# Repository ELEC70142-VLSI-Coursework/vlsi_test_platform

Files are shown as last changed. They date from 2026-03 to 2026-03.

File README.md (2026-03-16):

# VLSI Test Platform

A complete hardware and software solution for bringing up and testing the VLSI SoC Project IC. This repository contains the FPGA firmware, Python host tools, and hardware design documentation.

## System Overview

The test platform consists of three integrated components:

<div align="center">
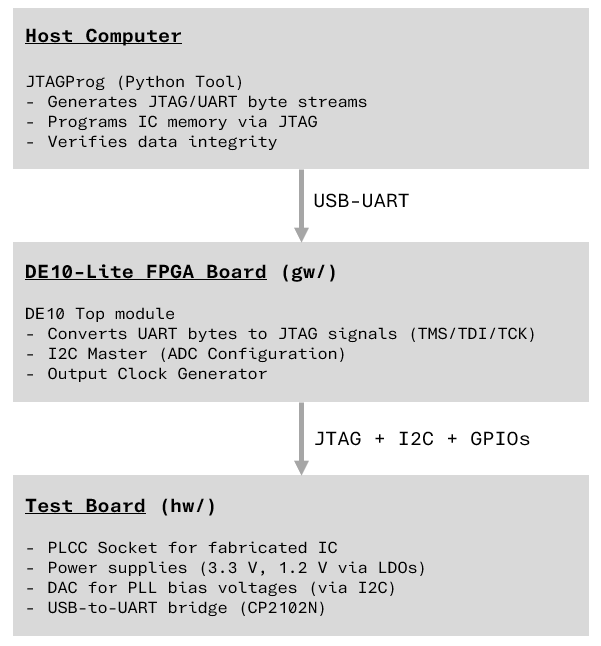
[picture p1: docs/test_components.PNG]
    
</div>

## Directory Structure

```
vlsi_test_platform/
├── gw/                    # FPGA Firmware (DE10-Lite)
│   ├── src/              # SystemVerilog modules
│   │   ├── DE10Top.sv    # Top-level module
│   │   ├── jtag_uart_bridge.sv
│   │   ├── jtag_engine.sv
│   │   ├── adc_commander.sv
│   │   ├── i2c_master.sv
│   │   └── uart_*.sv     # UART controller modules
│   ├── test/             # DUT (Device Under Test) bitstreams
│   └── README.md         # FPGA documentation
│
├── sw/                    # Host-Side Python Tools
│   ├── JTAGProg.py       # JTAG programmer and tester
│   └── README.md         # Python tool documentation
│
├── hw/                    # Test Board PCB Design
│   ├── [Schematic/Layout files]
│   └── README.md         # Hardware documentation
│
└── README.md             # This file
```

## Quick Start

### Prerequisites

1. **Hardware**: DE10-Lite FPGA board and VLSI test board
2. **Software**: Quartus Prime, Python 3.6+, pyserial

### 1. Program the FPGA

1. Load the compiled FPGA design (`.sof` file) onto the DE10-Lite using Quartus Programmer
2. The FPGA automatically configures the test board DAC after reset
3. Verify that the USB-UART bridge is recognized on your host computer

### 2. Program the IC via JTAG

```bash
# Test mode: verify JTAG communication with a known pattern
python JTAGProg.py COM4 --test-mode --word-count 256

# Load mode: program memory from a hex file
python JTAGProg.py COM4 program.hex
```

See [sw/README.md](sw/README.md) for full usage details.

### 3. Verify the Setup

- Check that the test board LEDs indicate correct power and USB connection
- Monitor JTAG read/write throughput in the python interface output
- Inspect the IC power supplies and clock signals with an oscilloscope if needed

## Component Details

### FPGA Firmware (gw/)

The DE10-Lite FPGA implements:
- **UART-to-JTAG Bridge**: Converts serial bytes to JTAG protocol for IC programming
- **I2C Master**: Configures the DAC for PLL bias voltages
- **Clock Generator**: Produces a test clock output

[Read more](gw/README.md)

### Python Host Tool (sw/)

`JTAGProg.py` provides:
- **Test Mode**: Random write/read verification for JTAG communication
- **Load Mode**: Program IC memory from a plain-text hex file
- **Performance Monitoring**: Reports read/write throughput and errors

[Read more](sw/README.md)

### Test Board Hardware (hw/)

The PCB includes:
- PLCC socket for the VLSI IC
- Power management (3.3 V and 1.2 V LDOs)
- DAC for PLL bias voltage tuning
- USB-to-UART bridge (CP2102N)
- FPGA connector for control signals (JTAG, I2C, clock)
- Reset button and DIP switch for PLL frequency selection

[Read more](hw/README.md)

## References

- Altera DE10-Lite Board: [User Manual](https://www.intel.com/content/www/us/en/programmable/documentation/boards/de10_lite_user_manual.pdf)
- CP2102N USB-UART IC: [Datasheet](https://www.silabs.com/documents/public/data-sheets/cp2102n-datasheet.pdf)
- DAC7578 DAC IC: [Datasheet](https://www.ti.com/lit/ds/symlink/dac7578.pdf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)

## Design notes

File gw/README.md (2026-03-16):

# FPGA Control Firmware for VLSI Test Platform

This directory contains the SystemVerilog modules that implement the control firmware for the VLSI Module Project IC test platform. The design runs on the DE10-Lite FPGA board and provides the following core functionality:

- **ADC Configuration**: Configures the bias voltages for the PLL via I2C protocol
- **UART-to-JTAG Bridge**: Bridges serial communication to JTAG for IC programming and testing
- **Generated Clock Output**: Provides a configurable clock signal for testing

## Module Overview

| Module | File | Purpose |
|---|---|---|
| `DE10Top` | `DE10Top.sv` | Top-level module integrating all components |
| `adc_commander` | `adc_commander.sv` | Manages I2C communication with the ADC for PLL bias voltage configuration |
| `i2c_master` | `i2c_master.sv` | I2C protocol controller |
| `jtag_uart_bridge` | `jtag_uart_bridge.sv` | Converts UART byte stream to JTAG signals (TMS, TDI, TCK, TDO) |
| `jtag_engine` | `jtag_engine.sv` | Low-level JTAG state machine controller |
| `uart_rx` / `uart_tx` | `uart_rx.sv`, `uart_tx.sv` | UART serial communication |
| `rx_fifo` / `tx_fifo` | `rx_fifo.sv`, `tx_fifo.sv` | Synchronous FIFOs for UART buffering |

## Clock Generation

The design generates an internal 10 MHz clock using the Quartus PLL IP (`pll_clk`). An additional output clock (`clk_out`) is generated at 100 kHz and output to pin Y5 (IC package pin 43). The output clock frequency can be modified by changing the `OUTPUT_CLK_FREQ` parameter in `DE10Top.sv`.

**Note**: The Quartus IP generator may not generate the PLL IP correctly. Verify that the output frequency matches the expected value before deployment.

## I2C and ADC Commander

The ADC on the test board configures the PLL bias voltages via the I2C protocol. The `adc_commander` module orchestrates this configuration by sending commands through the `i2c_master` module.

- **Bias Voltage Configuration**: Two 12-bit voltage values are configured via I2C
- **Experimental Tuning**: Voltage values should be calibrated based on measurements on the actual IC

For details on command sequences, refer to `adc_commander.sv`.

## UART Connectivity

The test board includes a USB-UART bridge IC (CP2102N) connected to the FPGA:

| FPGA Port | CP2102N Pin | Direction |
|---|---|---|
| `uart_rx` | Y6 | Input (from host) |
| `uart_tx` | Y7 | Output (to host) |

**Note**: Pin assignments swap the physical connections; the FPGA perspective labels (`uart_rx`, `uart_tx`) correctly represent the data flow.

Pin assignments in the `.qpf` file:
```
set_location_assignment PIN_Y6 -to uart_rx
set_location_assignment PIN_Y7 -to uart_tx
```

## UART-to-JTAG Bridge

The `jtag_uart_bridge` module converts UART byte stream to JTAG protocol signals for IC programming and testing. Each UART byte is interpreted as:
- **High nibble (bits 7-4)**: Four TMS bits
- **Low nibble (bits 3-0)**: Four TDI bits

The `jtag_engine` module implements the JTAG state machine and handles TCK generation.

A Python driver for communicating with the bridge is provided in the `/sw` folder.

## Customizing the Design

The FPGA can be extended to drive IC inputs and process outputs based on project specifications:
- **UART Redirection**: Redirect UART ports to IC GPIO through the FPGA fabric
- **Preserve ADC Configuration**: The `adc_commander` module is required for correct PLL operation
- **Extending Functionality**: Additional logic can be instantiated in parallel with existing modules

### Pin Assignments

The following pin constraints are required for the test board:

```
set_location_assignment PIN_V7 -to rst_n
set_location_assignment PIN_P11 -to pll_clk
set_location_assignment PIN_Y6 -to uart_rx
set_location_assignment PIN_Y7 -to uart_tx
set_location_assignment PIN_W11 -to sda
set_location_assignment PIN_AA10 -to scl
set_location_assignment PIN_Y5 -to clk_out 
```

All pin IO Standard must be configured on `3.3-V LVTTL`.

Mapping of pins between FPGA and IC can be found in the board [schematic](../hw/schematic.pdf)

## Testing the JTAG Interface

To test the JTAG functionality with a simulated IC memory model:

1. Prepare a second DE10-Lite board to act as a Device Under Test (DUT)
2. Load the DUT bitstream via Quartus > Tools > Programmer
3. Connect the DUT to the test board's DUT connector
4. Use the Python script (in `/sw`) to program through the UART-JTAG bridge

**Bitstream Files**:
- `.sof` (SRAM Object File): Loaded directly into FPGA RAM; erased on power-off
- `.pof` (Programmer Object File): Stored in flash memory; persists across power cycles

Use `.pof` to retain the FPGA design after power-off.

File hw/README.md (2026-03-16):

# Testboard Hardware

The testboard is an integrated solution for the **VLSI SoC Project** IC bring-up. It includes:

- PLCC socket
- LDOs for the padring and core supplies (3.3 V and 1.2 V respectively)
- Reset button
- Solderable jumper to select active-high or active-low reset
- 25 MHz crystal oscillator
- DAC to supply bias voltages to the PLL
- 4-position DIP switch for selecting the PLL frequency
- USB-to-UART bridge IC (CP2102N)
- Jumpers to select the source of the clock and 1.2 V supply (board or connector)
- Buffers for the FPGA input clock and the board output clock
- Connector for the DE10-Lite FPGA

<div align="center">
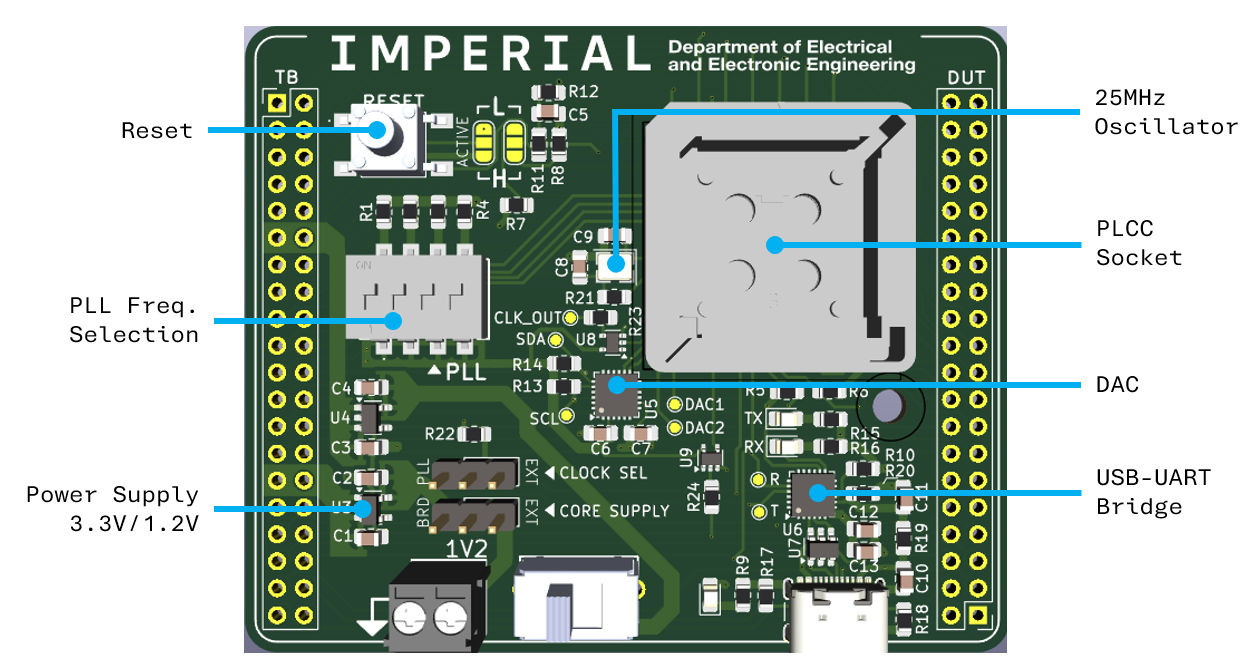
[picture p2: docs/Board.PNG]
    
</div>

## Assembly Guidelines

First, solder the SMD components using the stencil and a reflow oven. Do not place the DIP switch in the reflow oven — solder it by hand afterwards.

Once the SMD components are soldered, test the LDOs by applying 5 V and 3.3 V to connector U1 (TB). Check for shorts on the USB-C connector and verify that QFN packages U5 and U6 have no solder bridges and all pins are properly soldered. 

Set solder jumpers JP4 and JP5 to the low position, marked "L" on the silkscreen.

Next, solder the through-hole components: power switch S2, connector J2, jumpers JP1 and JP2, and the 40-pin FPGA connectors. Do not solder the PLCC socket (J4) at this stage — leaving it unsoldered allows easier access to the pin holes for testing.

Once testing is complete, solder the PLCC socket with the orientation arrow pointing down, indicating pin 1.

### Testing the DAC

The I2C DAC IC can be tested by connecting a DE10-Lite FPGA board and loading the bitstream described elsewhere in this repository. The FPGA automatically configures the DAC over I2C after reset. The DAC requires the 1.2 V supply as its reference — ensure the core-supply jumper is set to "BRD" to use the onboard LDO. Measure the DAC outputs at testpoints DAC1 and DAC2; the expected voltages are defined in [gw/src/adc_commander.sv](../gw/src/adc_commander.sv).

### Testing the USB-UART Bridge

Test the USB-UART bridge using the provided FPGA design (see elsewhere in this repository). After loading the bitstream, verify UART–JTAG communication using the Python script.

The TX/RX LEDs (D2 and D3) will not function on a newly soldered CP2102N until the IC has been configured. To configure it:

1. Install the USB-to-UART VCP drivers from [Silicon Labs](https://www.silabs.com/software-and-tools/usb-to-uart-bridge-vcp-drivers?tab=downloads).
2. Install [Simplicity Studio 5](https://www.silabs.com/software-and-tools/simplicity-studio/simplicity-studio-version-5) (not version 6).
3. Power the board and launch Simplicity Studio — it should detect the CP2102N automatically.
4. Open **Tools > Express Configurator**.
5. Under **Configuration Groupings > Port Configurations > GPIO**, set GPIO0 to "TX Toggle" and GPIO1 to "RX Toggle".
6. Click **Program to Device**.

## Suggested Improvements

Future board revisions could include:

- Decoupling capacitors between the PLCC socket supply pins and ground.
- A silkscreen mark indicating PLCC socket pin 1.
- A small series resistor between the PLCC socket clock input and the Schmitt-trigger buffer to reduce ringing.
- Additional mounting holes.

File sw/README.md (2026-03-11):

# JTAGProg — Host-Side JTAG/UART Programmer

`JTAGProg.py` is a Python tool for driving the JTAG Engine firmware module located in [gw/src/](../gw/src/) via a UART interface. A USB-to-UART bridge (e.g. FTDI or CP2102N) exposes the JTAG engine to the host as a standard serial port.

## How it works

The script contains two main classes:

- **`JTAGDriver`** — builds TMS/TDI bitstreams and packs them into bytes. Each byte encodes four JTAG clock cycles: the high nibble carries four TMS bits and the low nibble carries four TDI bits. The class provides helpers for navigating the JTAG FSM and shifting instructions and data registers.
- **`JTAGProg`** — opens a serial port and sends/receives the packed byte stream to/from the UART bridge. Read data is recovered by clocking dummy bytes into the TAP and capturing the TDO bits returned by the target device.

## Dependencies

Install the required package with:

```
pip install pyserial
```

## Usage

Run the script with `-h` to see all options:

```
python JTAGProg.py -h
```

In both modes the COM port must be specified. To list available ports:

```
python -m serial.tools.list_ports -v
```

### Test mode

Generates random 32-bit words, writes them to memory, then reads them back and verifies the contents.

```
python JTAGProg.py COM4 --test-mode --word-count 256
```

`--word-count` is optional (default: 128).

### Load mode

Writes the contents of a plain-text file containing one 32-bit hex word per line.

```
python JTAGProg.py COM4 data.hex
```

### Output

Both modes print a summary after verification:

```
Summary:
  Total words: 256
  Total bytes: 1024 (1.00 KB)
  Total write time: 1.604s
  Write throughput: 0.62 KB/s
  Total read time: 6.994s
  Read throughput: 0.14 KB/s
  Total errors: 0
```

The script exits with code `2` if any verification errors are detected, or `0` on success.

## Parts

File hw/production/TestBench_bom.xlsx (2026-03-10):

 |  |  |  |  |  |  |  |  |  | 10
Reference | Value | Footprint | Qty | Supplier | Other Supplier | SupplierPartNo | Description | UnitPrice | MinQty | Quantity | LineSum | Link
C1,C2,C4 | 1u | Capacitor_SMD:C_0805_2012Metric_Pad1.18x1.45mm_HandSolder | 3 | OneCall (Farnell and CPC) |  | 3013482 | £0.0679 - SMD Multilayer Ceramic Capacitor, 1 µF, 50 V, 0805 [2012 Metric], ± 10%, X7R | 0.046978 | 10 | 30 | 1.41 | https://uk.farnell.com/samsung-electro-mechanics/cl21b105kbfnnne/cap-1uf-50v-mlcc-0805/dp/3013482
C3,C10,C13 | 10u | Capacitor_SMD:C_0805_2012Metric_Pad1.18x1.45mm_HandSolder | 3 | OneCall (Farnell and CPC) |  | 3013485 | £0.1488 - SMD Multilayer Ceramic Capacitor, 10 µF, 16 V, 0805 [2012 Metric], ± 10%, X7R | 0.10292 | 10 | 30 | 3.09 | https://uk.farnell.com/samsung-electro-mechanics/cl21b106koqnnne/cap-10uf-16v-mlcc-0805/dp/3013485
C5,C6,C7,C11,C12 | 100n | Capacitor_SMD:C_0805_2012Metric_Pad1.18x1.45mm_HandSolder | 5 | OneCall (Farnell and CPC) |  | 4539029 | £0.0329 - SMD Multilayer Ceramic Capacitor, 0.1 µF, 50 V, 0805 [2012 Metric], ± 10%, X7R | 0.013114 | 10 | 50 | 0.66 | https://uk.farnell.com/samsung-electro-mechanics/cl21b104kbcnnnd/capacitor-mlc-0-1uf-x7r-50v-0805/dp/4539029
C8,C9 | 6p | Capacitor_SMD:C_0805_2012Metric_Pad1.18x1.45mm_HandSolder | 2 | OneCall (Farnell and CPC) |  | 1759185 | £0.054 - SMD Multilayer Ceramic Capacitor, 6 pF, 50 V, 0805 [2012 Metric], ± 0.5pF, C0G / NP0 | 0.054 | 10 | 20 | 1.08 | https://uk.farnell.com/multicomp-pro/mc0805n6r0d500ct/cap-6pf-50v-c0g-np0-0805/dp/1759185
D1,D2,D3 | LED | LED_SMD:LED_0805_2012Metric_Pad1.15x1.40mm_HandSolder | 3 | OneCall (Farnell and CPC) |  | 1226392 | £0.1548 - LED, Hyper-Bright, Red, SMD, 0805 [2012 Metric], 25 mA, 2 V, 633 nm | 0.108 | 10 | 30 | 3.24 | https://uk.farnell.com/osram-opto-semiconductors/lsr976/led-0805-red-50mcd-632nm/dp/1226392
J2 | Conn_01x02_Socket | Footprints:CTB30512BK | 1 | OneCall (Farnell and CPC) |  | 3882615 | £0.5508 - Wire-To-Board Terminal Block, 3.5 mm, 2 Ways, 1 mm², Screw | 0.5508 | 1 | 10 | 5.51 | https://uk.farnell.com/camdenboss/ctb3051-2bk/terminal-block-wire-to-brd-2pos/dp/3882615
J4 | 54020-44030LF | Footprints:5402044030LF | 1 | OneCall (Farnell and CPC) |  | 3881743 | £2.55 - IC & Component Socket, 44 Contacts, PLCC Socket, 2.54 mm, FCI 54020 Series, 2.54 mm, Copper Alloy | 2.55 | 1 | 10 | 25.50 | https://uk.farnell.com/amphenol-fci/54020-44030lf/conn-plcc-socket44pos-2-54mm/dp/3881743
J5 | USB_C_Receptacle_USB2.0_16P | Connector_USB:USB_C_Receptacle_GCT_USB4105-xx-A_16P_TopMnt_Horizontal | 1 | OneCall (Farnell and CPC) |  | 3588205 | £0.744 - USB Connector, 5A, 48V, 240W, USB Type C, USB 2.0, Receptacle, 16 Ways | 0.744 | 1 | 10 | 7.44 | https://uk.farnell.com/gct-global-connector-technology/usb4105-gf-a/usb-conn-2-0-type-c-rcpt-16pos/dp/3588205
R1,R2,R3,R4,R5,R6,R7,R8,R13,R14,R22 | 4k2 | Resistor_SMD:R_0805_2012Metric_Pad1.20x1.40mm_HandSolder | 11 | OneCall (Farnell and CPC) |  | 3952297 | £0.012 - SMD Chip Resistor, 4.3 kohm, ± 5%, 125 mW, 0805 [2012 Metric], Thick Film, General Purpose | 0.008 | 10 | 110 | 0.88 | https://uk.farnell.com/yageo/rc0805jr-074k3l/res-4k3-5-0-125w-thick-film-0805/dp/3952297
R9,R15,R16 | 330R | Resistor_SMD:R_0805_2012Metric_Pad1.20x1.40mm_HandSolder | 1 | OneCall (Farnell and CPC) |  | 2447638 | £0.0156 - SMD Chip Resistor, 330 ohm, ± 1%, 125 mW, 0805 [2012 Metric], Thick Film, General Purpose | 0.0156 | 10 | 10 | 0.16 | https://uk.farnell.com/multicomp-pro/mcwr08x3300ftl/res-330r-1-0-125w-0805-thick-film/dp/2447638
R23, R24 | 33R | Resistor_SMD:R_0805_2012Metric_Pad1.20x1.40mm_HandSolder | 1 | OneCall (Farnell and CPC) |  | 2447640 | £0.0156 - SMD Chip Resistor, 33 ohm, ± 1%, 125 mW, 0805 [2012 Metric], Thick Film, General Purpose | 0.0156 | 10 | 10 | 0.16 | https://uk.farnell.com/multicomp-pro/mcwr08x33r0ftl/res-33r-1-0-125w-thick-film/dp/2447640
R10 | 1k | Resistor_SMD:R_0805_2012Metric_Pad1.20x1.40mm_HandSolder | 1 | OneCall (Farnell and CPC) |  | 2447587 | £0.0156 - SMD Chip Resistor, 1 kohm, ± 1%, 125 mW, 0805 [2012 Metric], Thick Film, General Purpose | 0.0156 | 10 | 10 | 0.16 | https://uk.farnell.com/multicomp-pro/mcwr08x1001ftl/res-1k-1-0-125w-0805-thick-film/dp/2447587
R11,R12 | 100R | Resistor_SMD:R_0805_2012Metric_Pad1.20x1.40mm_HandSolder | 2 | OneCall (Farnell and CPC) |  | 9332375 | £0.0139 - SMD Chip Resistor, 100 ohm, ± 1%, 100 mW, 0805 [2012 Metric], Thick Film, General Purpose | 0.00928 | 10 | 20 | 0.19 | https://uk.farnell.com/multicomp-pro/mc01w08051100r/res-100r-1-0-1w-0805-thick-film/dp/9332375
R17,R18 | 5.1k | Resistor_SMD:R_0805_2012Metric_Pad1.20x1.40mm_HandSolder | 2 | OneCall (Farnell and CPC) |  | 2447692 | £0.0156 - SMD Chip Resistor, 5.1 kohm, ± 1%, 125 mW, 0805 [2012 Metric], Thick Film, General Purpose | 0.0156 | 10 | 20 | 0.31 | https://uk.farnell.com/multicomp-pro/mcwr08x5101ftl/res-5k1-1-0-125w-0805-thick-film/dp/2447692
R19 | 22.1k | Resistor_SMD:R_0805_2012Metric_Pad1.20x1.40mm_HandSolder | 1 | OneCall (Farnell and CPC) |  | 2447607 | £0.0156 - SMD Chip Resistor, 22 kohm, ± 1%, 125 mW, 0805 [2012 Metric], Thick Film, General Purpose | 0.0156 | 10 | 10 | 0.16 | https://uk.farnell.com/multicomp-pro/mcwr08x2202ftl/res-22k-1-0-125w-0805-thick-film/dp/2447607
R20 | 47.5k | Resistor_SMD:R_0805_2012Metric_Pad1.20x1.40mm_HandSolder | 1 | OneCall (Farnell and CPC) |  | 2447665 | £0.0156 - SMD Chip Resistor, 47.5 kohm, ± 1%, 125 mW, 0805 [2012 Metric], Thick Film, General Purpose | 0.0156 | 10 | 10 | 0.16 | https://uk.farnell.com/multicomp-pro/mcwr08x4752ftl/res-47k5-1-0-125w-thick-film/dp/2447665
R21 | 0R | Resistor_SMD:R_0805_2012Metric_Pad1.20x1.40mm_HandSolder | 1 | OneCall (Farnell and CPC) |  | 4312018 | £0.0139 - Zero Ohm Resistor, Jumper, 0805 [2012 Metric], Thick Film, 125 mW, 2 A, Surface Mount Device | 0.00928 | 10 | 10 | 0.09 | https://uk.farnell.com/yageo/rc0805fr-130rl/res-2a-0-125w-thick-film-0805/dp/4312018
U4 | MIC5504-3.3YM5 | Package_TO_SOT_SMD:SOT-23-5 | 1 | OneCall (Farnell and CPC) |  | 2510377 | £0.144 - Fixed LDO Voltage Regulator, 2.5V to 5.5V, 160mV Dropout, 3.3Vout, 300mAout, SOT-23-5 | 0.144 | 1 | 10 | 1.44 | https://uk.farnell.com/microchip/mic5504-3-3ym5-tr/ldo-fixed-3-3v-0-3a-40-to-125/dp/2510377
U6 | CP2102N-Axx-xQFN24 | Package_DFN_QFN:QFN-24-1EP_4x4mm_P0.5mm_EP2.6x2.6mm | 1 | OneCall (Farnell and CPC) |  | 3013847 | £3.22 - Interface Bridges, USB to UART, 3 V, 3.6 V, QFN, 24 Pins, -40 °C | 3.22 | 1 | 10 | 32.20 | https://uk.farnell.com/silicon-labs/cp2102n-a02-gqfn24/usb-to-uart-bridge-40-to-85deg/dp/3013847
U7 | USBLC6-2SC6 | Package_TO_SOT_SMD:SOT-23-6 | 1 | OneCall (Farnell and CPC) |  | 1269406 | £0.368 - ESD Protection Device, 17 V, SOT-23, 6 Pins | 0.3684 | 1 | 10 | 3.68 | https://uk.farnell.com/stmicroelectronics/usblc6-2sc6/esd-protection-17v-sot-23/dp/1269406
U8 | 74LVC1G04 | Package_TO_SOT_SMD:SOT-353_SC-70-5 | 1 | OneCall (Farnell and CPC) |  | 1845218 | £0.016 - Logic IC, Inverter, Single, 1 Inputs, 5 Pins, SOT-353, 74LVC1G04 | 0.1016 | 1 | 10 | 1.02 | https://uk.farnell.com/diodes-inc/74lvc1g04se-7/logic-inverter-gate-single-sot353/dp/1845218
U9 | 74LVC1G17 | Package_TO_SOT_SMD:SOT-353_SC-70-5 | 1 | OneCall (Farnell and CPC) |  | 1893834 | £0.1034 - Schmitt Trigger Buffer, LVC Family, 1 Input, 32 mA, Totem Pole, 1.65V to 5.5V, SOT-353-5 | 0.1035 | 1 | 10 | 1.03 | https://uk.farnell.com/diodes-inc/74lvc1g17se-7/logic-schmitt-trig-buffer-sot353/dp/1893834
Y1 | Crystal_GND24 | Crystal:Crystal_SMD_3225-4Pin_3.2x2.5mm | 1 | OneCall (Farnell and CPC) |  | 3819756 | £0.6048 - Crystal, 25 MHz, SMD, 3.2mm x 2.5mm, 20 ppm, 8 pF, 10 ppm, ABM8W Series | 0.6048 | 1 | 10 | 6.05 | https://uk.farnell.com/abracon/abm8w-25-0000mhz-8-d1x-t3/crystal-25mhz-8pf-3-2mm-x-2-5mm/dp/3819756
S1 | ADE04S04 | Footprints:ADE04S04 | 1 | Other Supplier: Digikey | Digikey | 450-2040-ND | £1.18 - SWITCH SLIDE DIP SPST 0.1A 24V | 1.18 | 1 | 10 | 11.80 | https://www.digikey.co.uk/en/products/detail/te-connectivity-alcoswitch-switches/1825058-7/1021543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
S2 | SLW-118562-4A-N-D | Footprints:SLW1185624AND | 1 | Other Supplier: Digikey | Digikey | 2223-SLW-118562-4A-N-D-ND | £0.42 - 11.1 X 8.5 X 6.2 MM, 4 MM RAISED | 0.42 | 1 | 10 | 4.20 | https://www.digikey.at/en/products/detail/same-sky-formerly-cui-devices/SLW-118562-4A-N-D/24399210
SW1 | TS04-66-73-BK-100-SMT | Footprints:TS046665BK160SMT | 1 | Other Supplier: Digikey | Digikey | 2223-TS04-66-65-BK-160-SMT-ND | £0.13 - SWITCH TACTILE SPST-NO 0.05A 12V | 0.13 | 1 | 10 | 1.30 | https://www.digikey.co.uk/en/products/detail/same-sky-formerly-cui-devices/TS04-66-65-BK-160-SMT/15634253
U3 | MIC5504-1.2YM5 | Package_TO_SOT_SMD:SOT-23-5 | 1 | Other Supplier: Digikey | Digikey | 576-4878-1-ND | £0.12 - IC REG LINEAR 1.2V 300MA SOT23-5 | 0.12 | 1 | 10 | 1.20 | https://www.digikey.co.uk/en/products/detail/microchip-technology/MIC5504-1-2YM5-TR/5209401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
U5 | DAC7578xRGE | Package_DFN_QFN:QFN-24-1EP_4x4mm_P0.5mm_EP2.6x2.6mm | 1 | Other Supplier: Digikey | Digikey | 296-DAC7578SRGERCT-ND | £9.75 - IC DAC 12BIT V-OUT 24VQFN | 7.67 | 1 | 10 | 76.70 | https://www.digikey.co.uk/en/products/detail/texas-instruments/DAC7578SRGER/2596812
U1,U2 | ~ | Connector_PinHeader_2.54mm:PinHeader_2x20_P2.54mm_Vertical | 2 | Other Supplier: Digikey |  | SAM1212-20-ND | £2.77 - CONN RCPT 40POS 0.1 TIN PCB | 2.77 | 1 | 20 | 55.40 | https://www.digikey.co.uk/en/products/detail/samtec-inc/SSW-120-01-T-D/1112236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
Note:
Prices as of January 2026

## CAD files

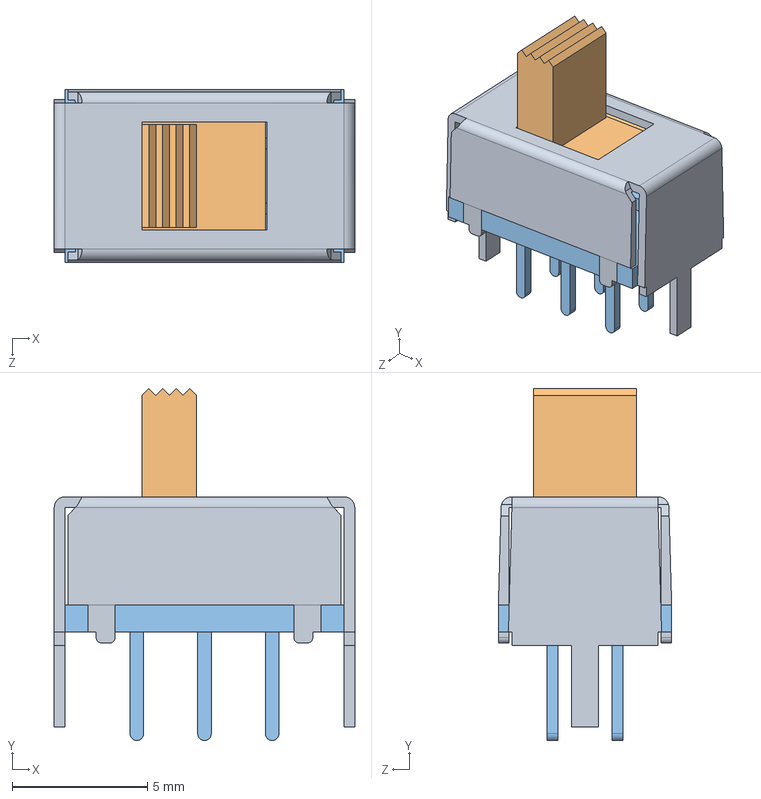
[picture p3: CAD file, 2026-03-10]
hw/kicad/3D_models/SLW-118562-4A-N-D.stp
11.1 x 13.0 x 6.40 mm

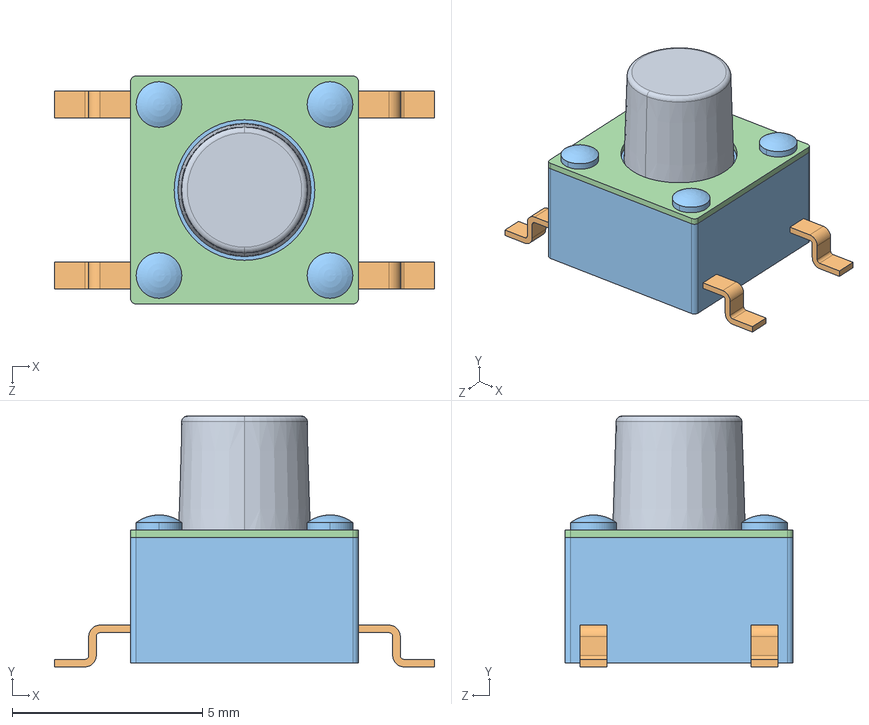
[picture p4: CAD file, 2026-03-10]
hw/kicad/3D_models/TS04-66-65-BK-160-SMT.stp
10.0 x 6.60 x 6.00 mm

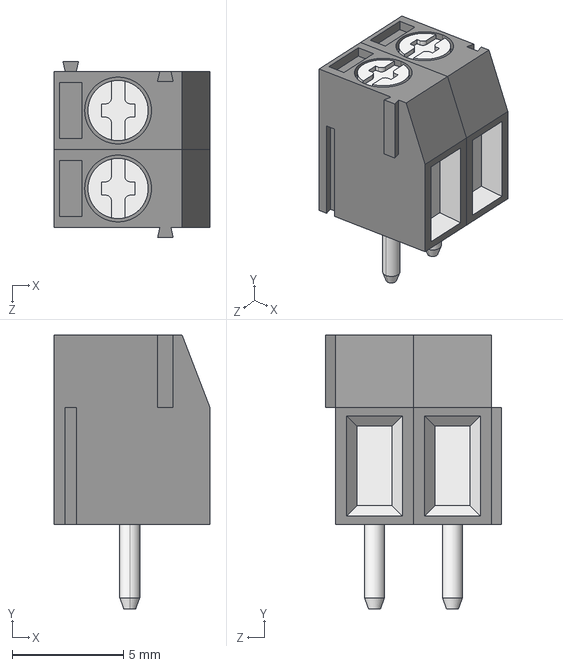
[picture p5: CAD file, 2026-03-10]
hw/kicad/3D_models/CTB3051_2BK.stp
7.00 x 12.3 x 7.90 mm

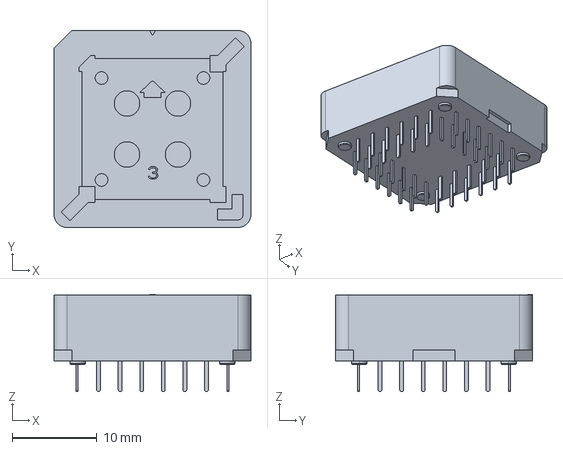
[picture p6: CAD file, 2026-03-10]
hw/kicad/3D_models/54020-44030LF.stp
23.2 x 23.2 x 11.4 mm

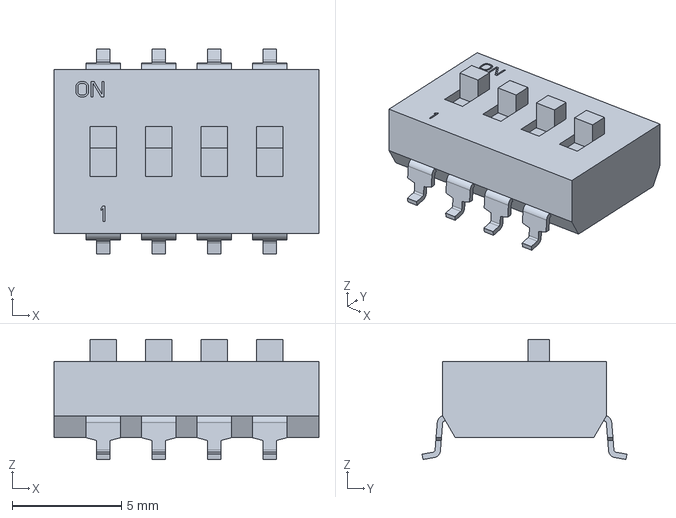
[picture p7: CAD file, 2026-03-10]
hw/kicad/3D_models/1825058-7.STEP
12.1 x 9.39 x 5.50 mm

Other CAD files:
hw/kicad/3D_models/1825058-7.stl

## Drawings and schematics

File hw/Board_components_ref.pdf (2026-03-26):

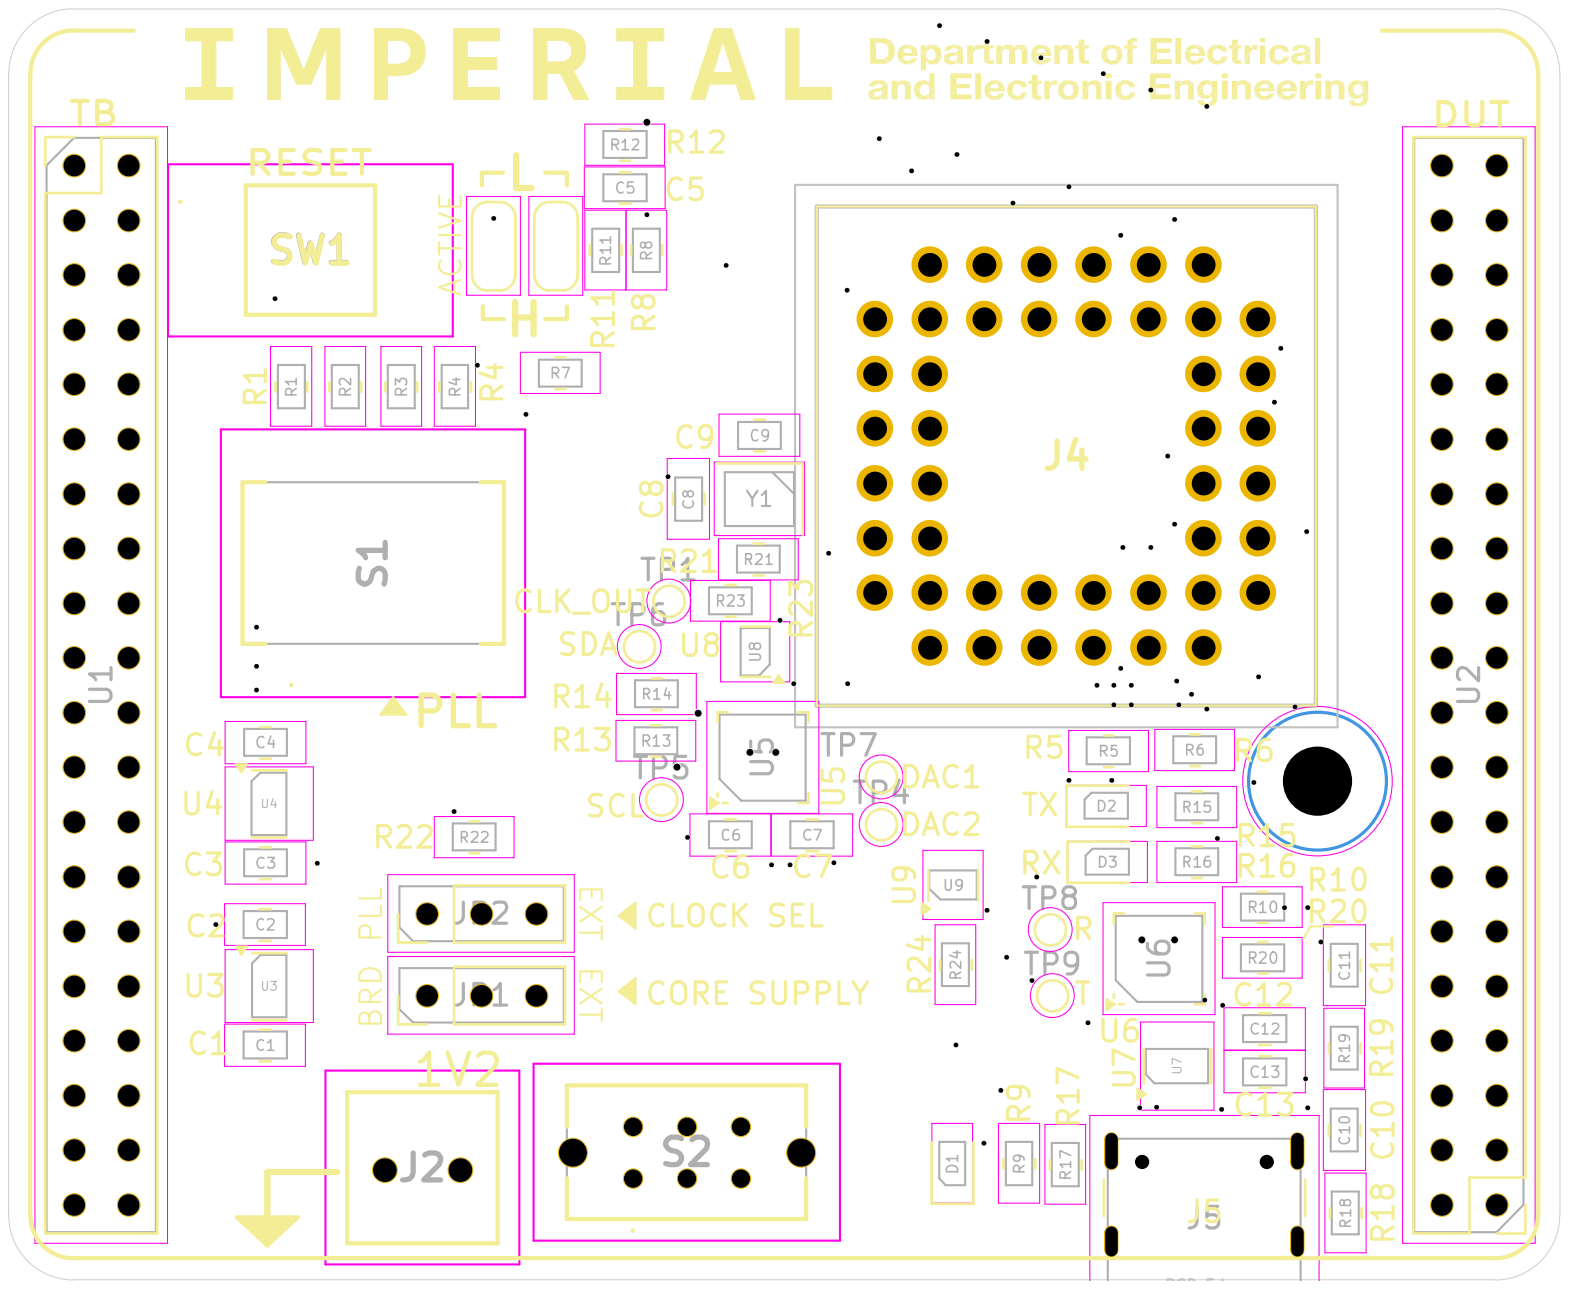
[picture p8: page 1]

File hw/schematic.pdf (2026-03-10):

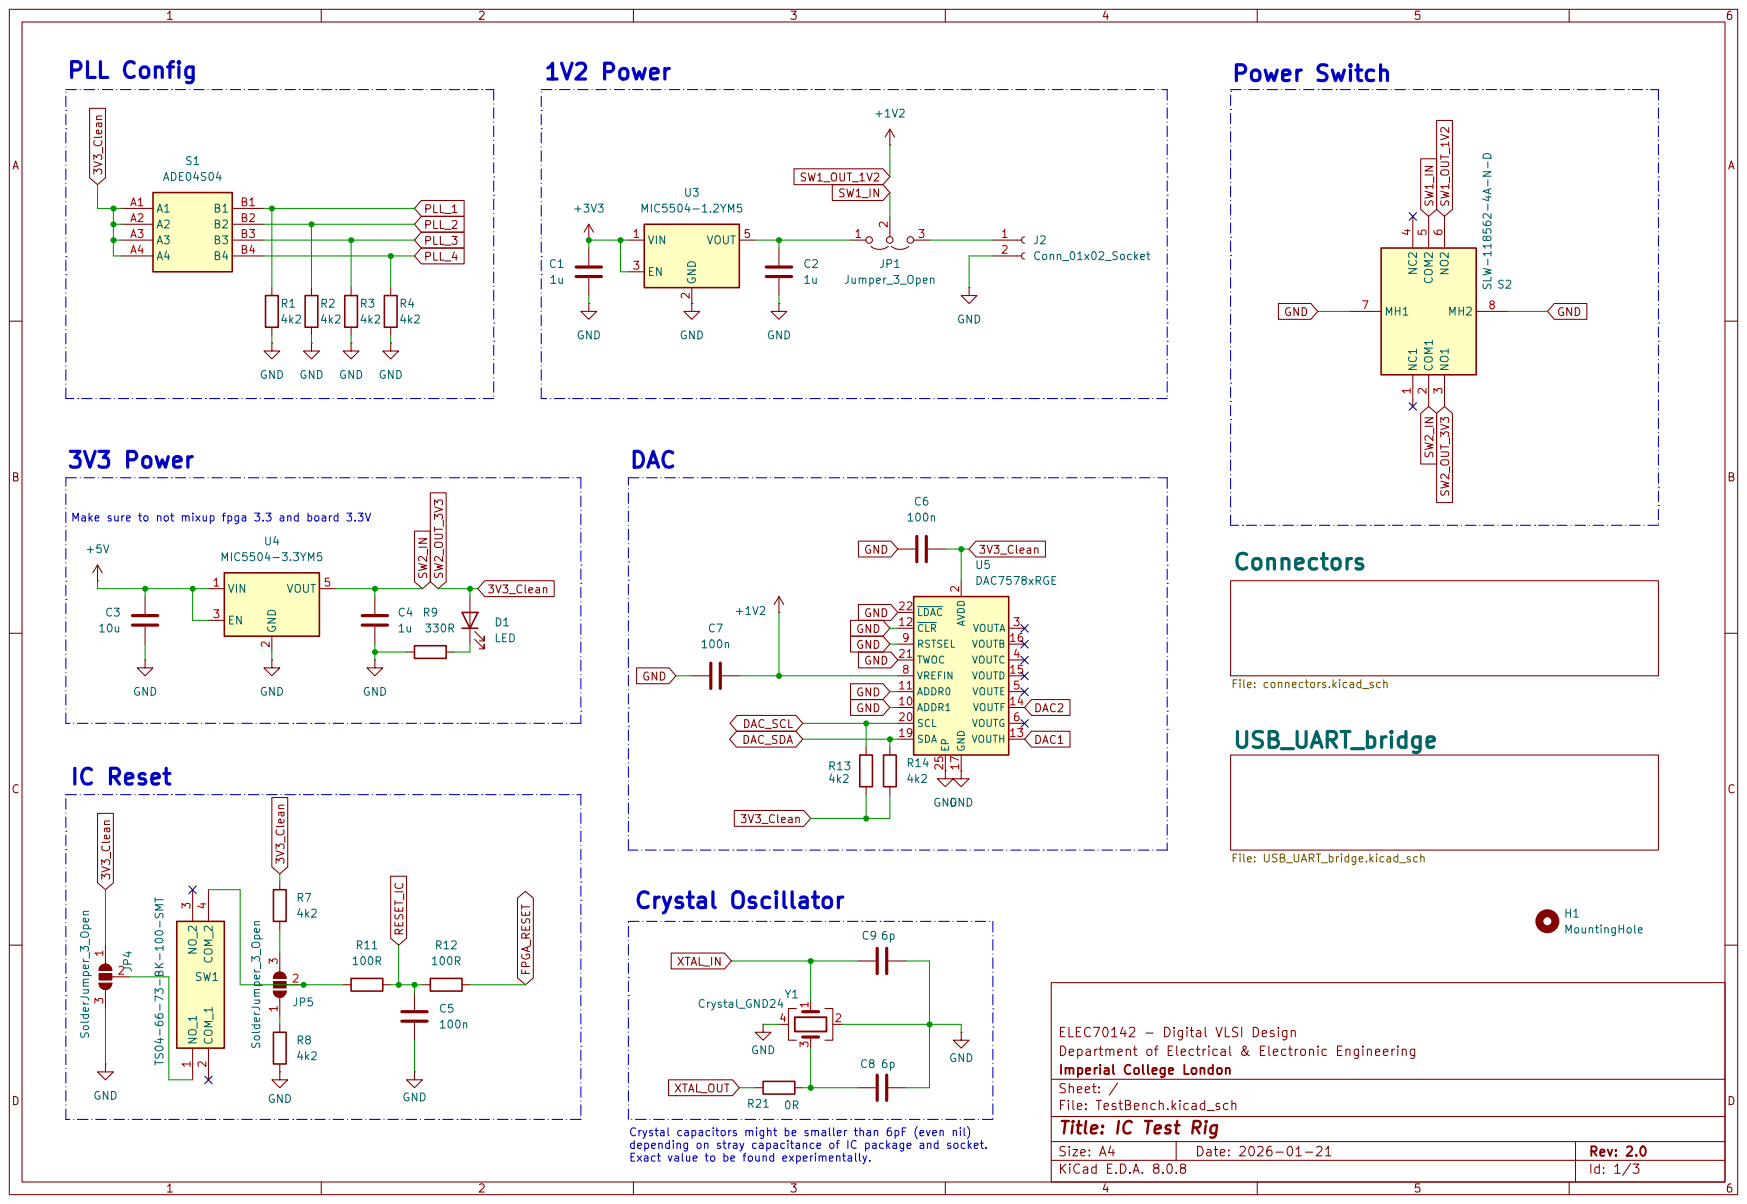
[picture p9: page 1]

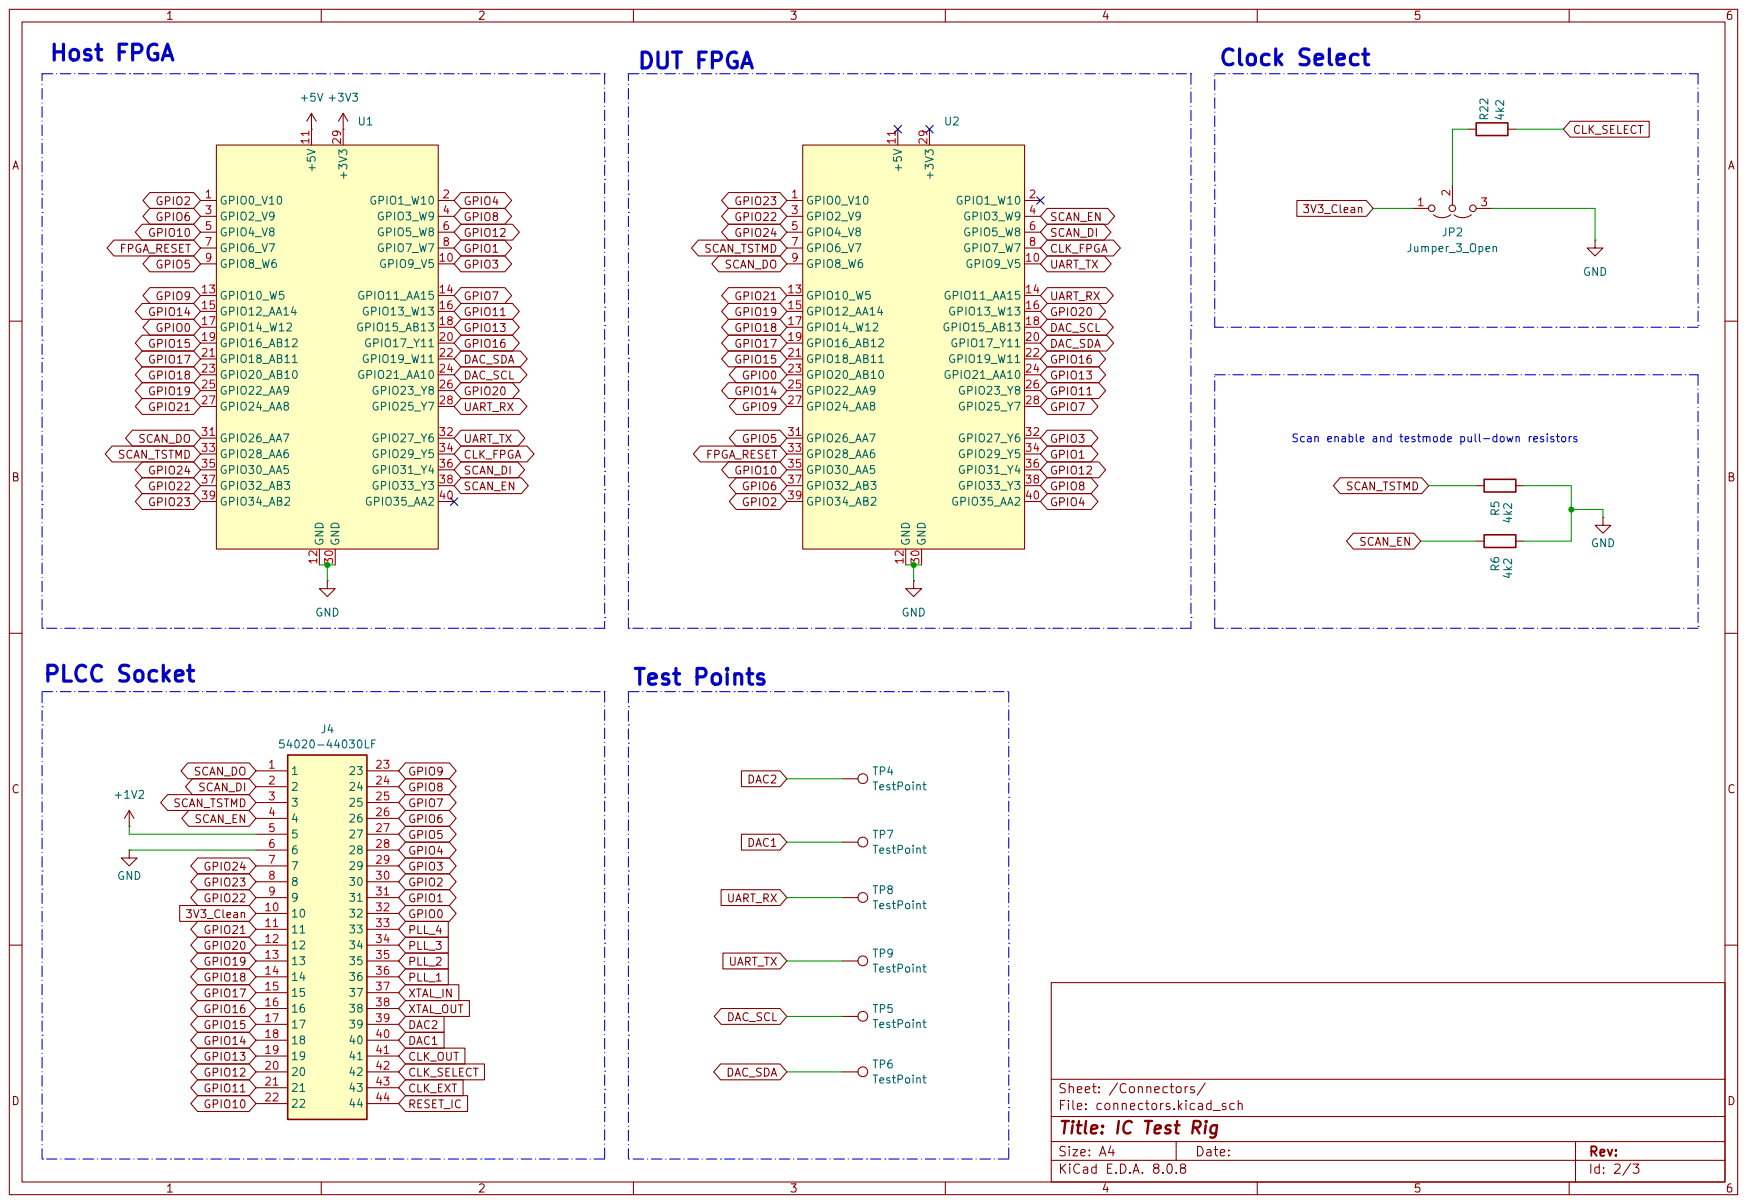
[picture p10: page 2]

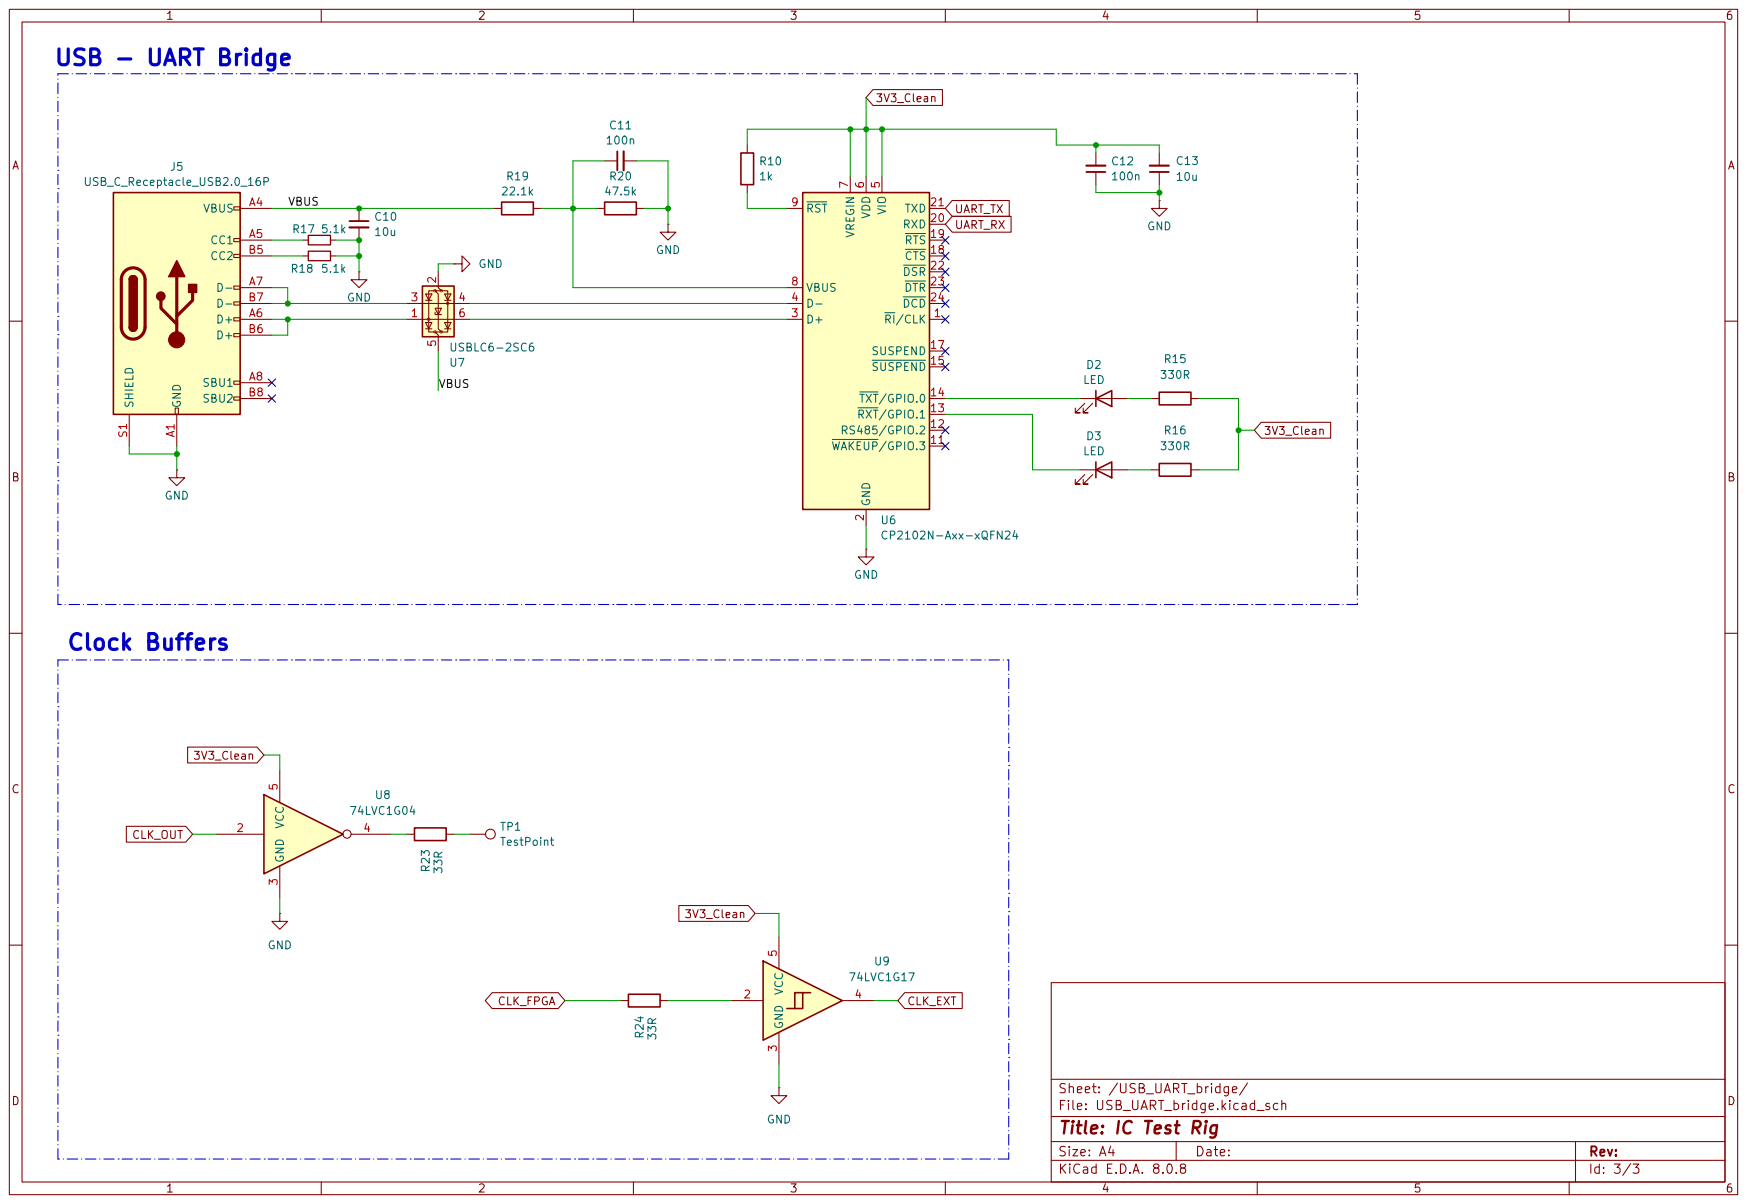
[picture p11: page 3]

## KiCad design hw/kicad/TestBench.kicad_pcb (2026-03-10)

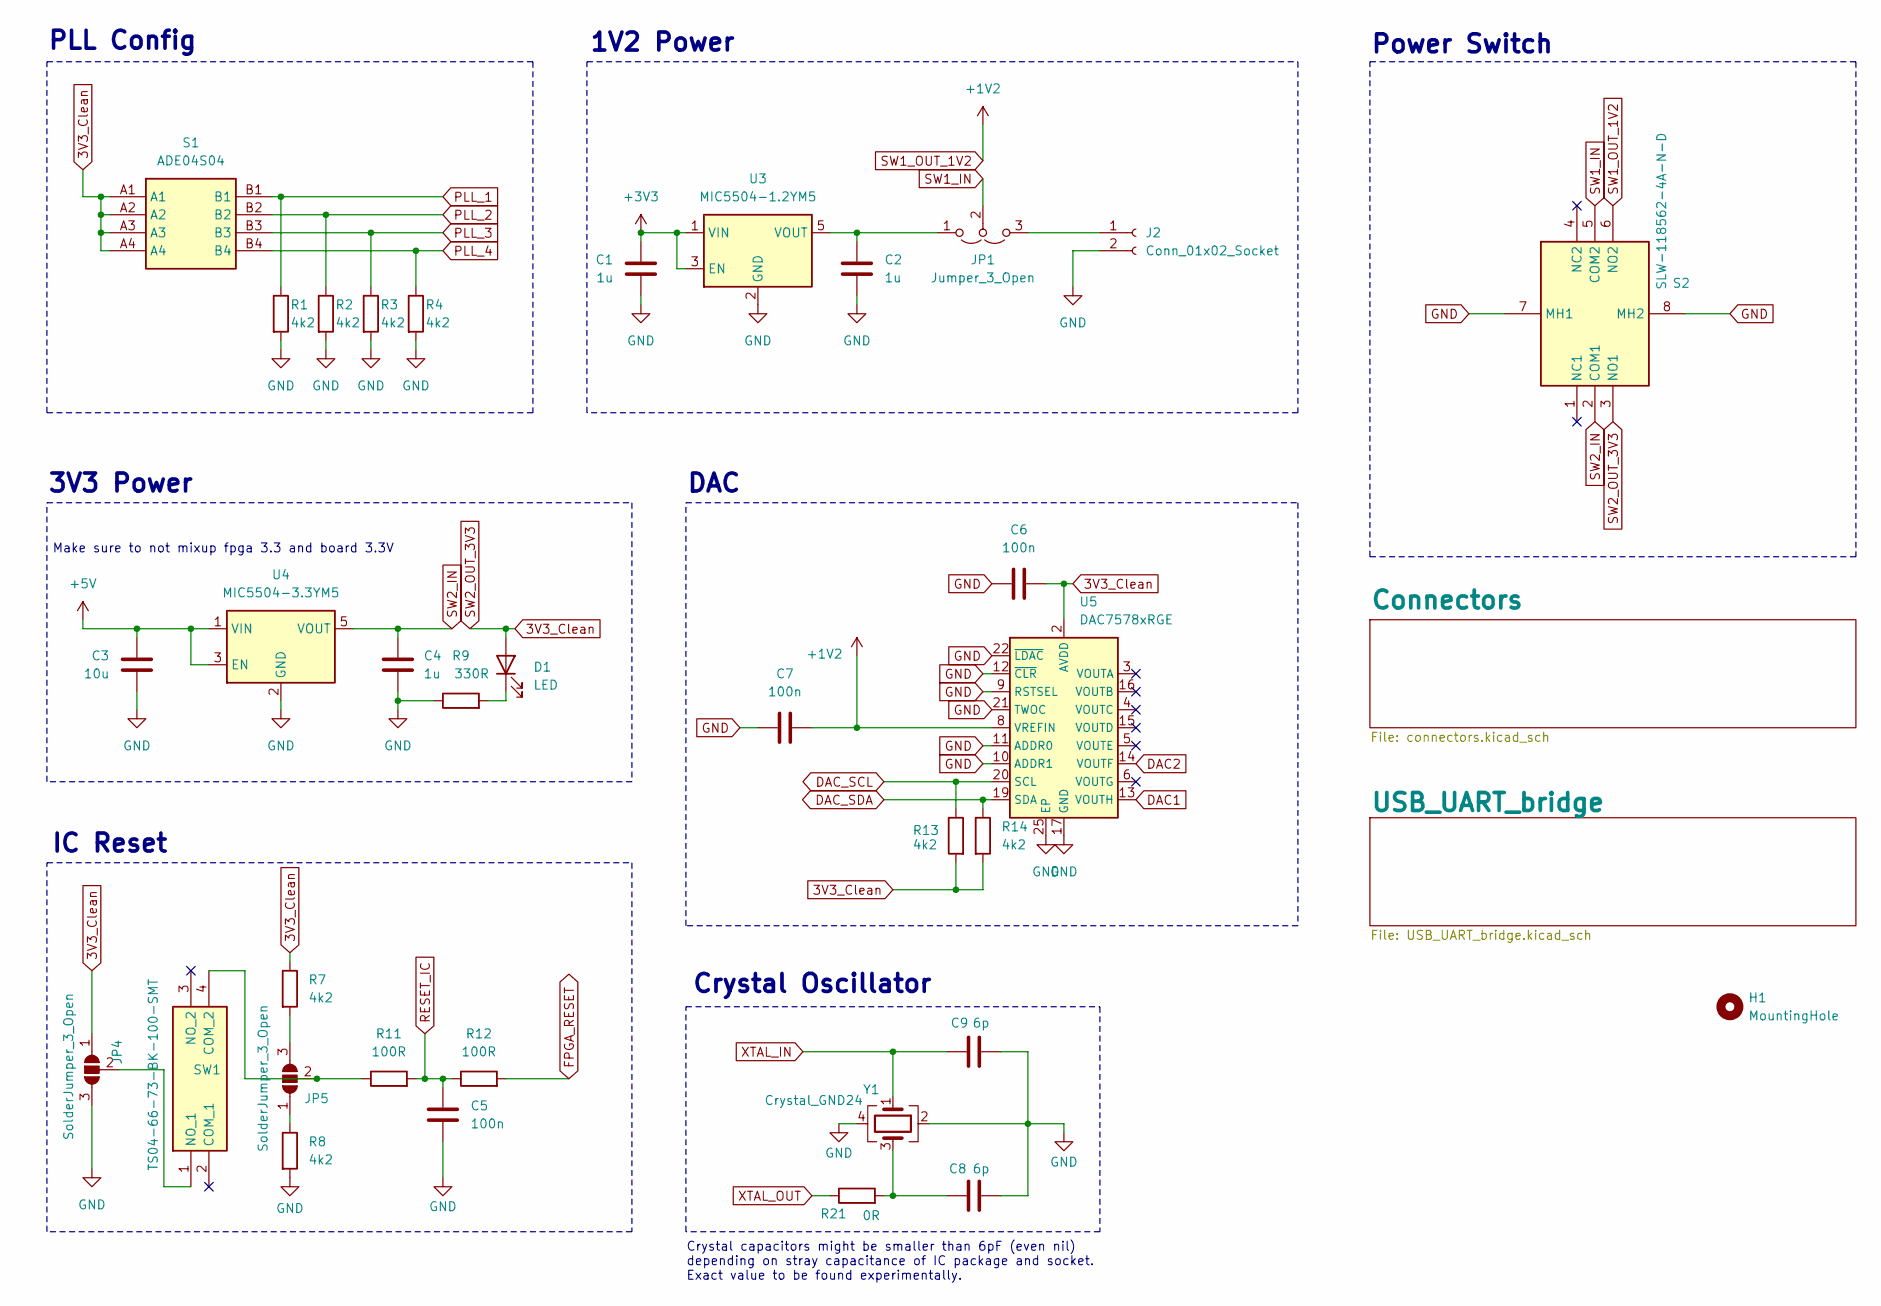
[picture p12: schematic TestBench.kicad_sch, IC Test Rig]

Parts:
C1, C2, C4: 1u; C_0805_2012Metric_Pad1.18x1.45mm_HandSolder
C3: 10u; C_0805_2012Metric_Pad1.18x1.45mm_HandSolder
C5, C6, C7: 100n; C_0805_2012Metric_Pad1.18x1.45mm_HandSolder
C8, C9: 6p; C_0805_2012Metric_Pad1.18x1.45mm_HandSolder
D1: LED; LED_0805_2012Metric_Pad1.15x1.40mm_HandSolder
H1: MountingHole; MountingHole_3.2mm_M3
J2: Conn_01x02_Socket; CTB30512BK
JP1: Jumper_3_Open; PinHeader_1x03_P2.54mm_Vertical
JP4, JP5: SolderJumper_3_Open; SolderJumper-3_P1.3mm_Open_RoundedPad1.0x1.5mm
R1, R2, R3, R4, R7, R8, R13, R14: 4k2; R_0805_2012Metric_Pad1.20x1.40mm_HandSolder
R9: 330R; R_0805_2012Metric_Pad1.20x1.40mm_HandSolder
R11, R12: 100R; R_0805_2012Metric_Pad1.20x1.40mm_HandSolder
R21: 0R; R_0805_2012Metric_Pad1.20x1.40mm_HandSolder
S1: ADE04S04; Mouser Part Number 506-ADE04S04
S2: SLW-118562-4A-N-D; SLW1185624AND; Mouser Part Number 179-SLW1185624AND
SW1: TS04-66-73-BK-100-SMT; TS046665BK160SMT; Mouser Part Number 179-TS046673BK100SMT
U3: MIC5504-1.2YM5; SOT-23-5
U4: MIC5504-3.3YM5; SOT-23-5
U5: DAC7578xRGE; QFN-24-1EP_4x4mm_P0.5mm_EP2.6x2.6mm
Y1: Crystal_GND24; Crystal_SMD_3225-4Pin_3.2x2.5mm

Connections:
3V3_Clean: C6.2, D1.2 (A), JP4.1 (A), R7.1, R13.2, R14.2, S1.A1, S1.A2, S1.A3, S1.A4, S2.3 (NO1), U5.2 (AVDD); also elsewhere on the board
+3V3: C1.1, U3.1 (VIN), U3.3 (EN); also elsewhere on the board
+5V: C3.1, U4.1 (VIN), U4.3 (EN); also elsewhere on the board
DAC1: U5.13 (VOUTH); also elsewhere on the board
DAC2: U5.14 (VOUTF); also elsewhere on the board
DAC_SCL: R13.1, U5.20 (SCL); also elsewhere on the board
DAC_SDA: R14.1, U5.19 (SDA); also elsewhere on the board
FPGA_RESET: R12.2; also elsewhere on the board
GND: C1.2, C2.2, C3.2, C4.2, C5.2, C6.1, C7.1, C8.2, C9.2, J2.2, JP4.3 (B), R1.2, R2.2, R3.2, R4.2, R8.2, R9.1, S2.7 (MH1), S2.8 (MH2), U3.2 (GND), U4.2 (GND), U5.9 (RSTSEL), U5.10 (ADDR1), U5.11 (ADDR0), U5.12 (~CLR), U5.17 (GND), U5.21 (TWOC), U5.22 (~LDAC), U5.25 (EP), Y1.2, Y1.4; also elsewhere on the board
unnamed: C8.1, R21.2, Y1.3
unnamed: D1.1 (K), R9.2
unnamed: J2.1, JP1.3 (B)
unnamed: C2.1, JP1.1 (A), U3.5 (VOUT)
unnamed: JP4.2 (C), SW1.1 (NO_1)
unnamed: JP5.1 (A), R8.1
unnamed: JP5.3 (B), R7.2
unnamed: JP5.2 (C), R11.1, SW1.4 (COM_2)
PLL_1: R1.1, S1.B1; also elsewhere on the board
PLL_2: R2.1, S1.B2; also elsewhere on the board
PLL_3: R3.1, S1.B3; also elsewhere on the board
PLL_4: R4.1, S1.B4; also elsewhere on the board
RESET_IC: C5.1, R11.2, R12.1; also elsewhere on the board
SW1_IN: JP1.2 (C), S2.5 (COM2)
SW1_OUT_1V2: C7.2, S2.6 (NO2), U5.8 (VREFIN); also elsewhere on the board
SW2_IN: C4.1, S2.2 (COM1), U4.5 (VOUT)
XTAL_IN: C9.1, Y1.1; also elsewhere on the board
XTAL_OUT: R21.1; also elsewhere on the board

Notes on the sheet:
DAC
Make sure to not mixup fpga 3.3 and board 3.3V
3V3 Power
Crystal capacitors might be smaller than 6pF (even nil) depending on stray capacitance of IC package and socket. Exact value to be found experimentally.
Power Switch
Crystal Oscillator
1V2 Power
IC Reset
PLL Config

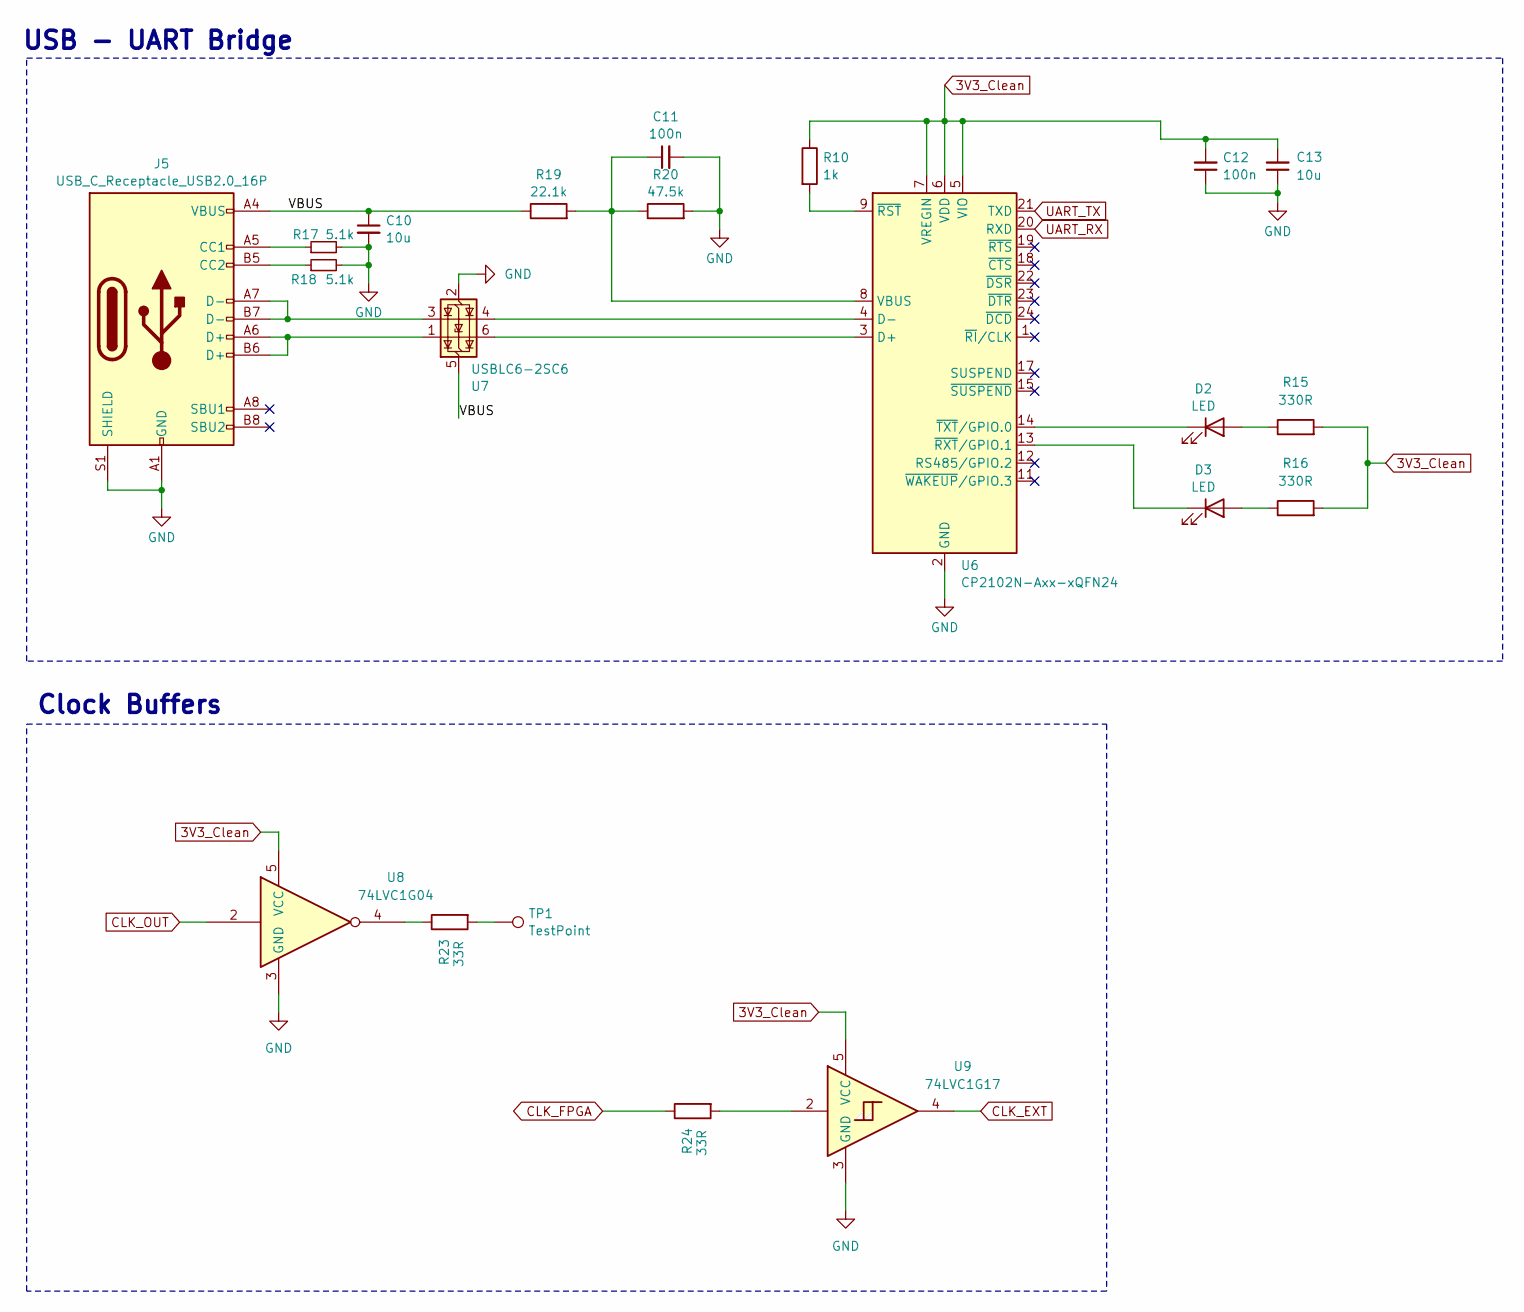
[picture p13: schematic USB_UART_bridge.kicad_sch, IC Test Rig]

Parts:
C10, C13: 10u; C_0805_2012Metric_Pad1.18x1.45mm_HandSolder
C11, C12: 100n; C_0805_2012Metric_Pad1.18x1.45mm_HandSolder
D2, D3: LED; LED_0805_2012Metric_Pad1.15x1.40mm_HandSolder
J5: USB_C_Receptacle_USB2.0_16P; USB_C_Receptacle_GCT_USB4105-xx-A_16P_TopMnt_Horizontal
R10: 1k; R_0805_2012Metric_Pad1.20x1.40mm_HandSolder
R15, R16: 330R; R_0805_2012Metric_Pad1.20x1.40mm_HandSolder
R17, R18: 5.1k; R_0805_2012Metric_Pad1.20x1.40mm_HandSolder
R19: 22.1k; R_0805_2012Metric_Pad1.20x1.40mm_HandSolder
R20: 47.5k; R_0805_2012Metric_Pad1.20x1.40mm_HandSolder
R23, R24: 33R; R_0805_2012Metric_Pad1.20x1.40mm_HandSolder
TP1: TestPoint; TestPoint_Pad_D1.0mm
U6: CP2102N-Axx-xQFN24; QFN-24-1EP_4x4mm_P0.5mm_EP2.6x2.6mm
U7: USBLC6-2SC6; SOT-23-6
U8: 74LVC1G04; SOT-353_SC-70-5
U9: 74LVC1G17; SOT-353_SC-70-5

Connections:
3V3_Clean: C12.2, C13.2, R10.1, R15.2, R16.2, U6.5 (VIO), U6.6 (VDD), U6.7 (VREGIN), U8.5 (VCC), U9.5 (VCC); also elsewhere on the board
/USB_UART_bridge/VBUS: C10.1, J5.A4 (VBUS), J5.A9 (VBUS), J5.B4 (VBUS), J5.B9 (VBUS), R19.1, U7.5 (VBUS)
CLK_EXT: U9.4; also elsewhere on the board
CLK_FPGA: R24.1; also elsewhere on the board
CLK_OUT: U8.2; also elsewhere on the board
GND: C10.2, C11.2, C12.1, C13.1, J5.A1 (GND), J5.A12 (GND), J5.B1 (GND), J5.B12 (GND), J5.S1 (SHIELD), R17.2, R18.2, R20.2, U6.2 (GND), U6.25 (GND), U7.2 (GND), U8.3 (GND), U9.3 (GND); also elsewhere on the board
unnamed: D2.2 (A), R15.1
unnamed: D2.1 (K), U6.14 (~TXT/GPIO.0)
unnamed: D3.2 (A), R16.1
unnamed: D3.1 (K), U6.13 (~RXT/GPIO.1)
unnamed: J5.A5 (CC1), R17.1
unnamed: J5.B5 (CC2), R18.1
unnamed: J5.A6 (D+), J5.B6 (D+), U7.1 (I/O1)
unnamed: J5.A7 (D-), J5.B7 (D-), U7.3 (I/O2)
unnamed: R23.1, U8.4
unnamed: R23.2, TP1.1
unnamed: R24.2, U9.2
unnamed: U6.3 (D+), U7.6 (I/O1)
unnamed: U6.4 (D-), U7.4 (I/O2)
unnamed: C11.1, R19.2, R20.1, U6.8 (VBUS)
unnamed: R10.2, U6.9 (~RST)
UART_RX: U6.20 (RXD); also elsewhere on the board
UART_TX: U6.21 (TXD); also elsewhere on the board

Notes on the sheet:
Clock Buffers
USB - UART Bridge

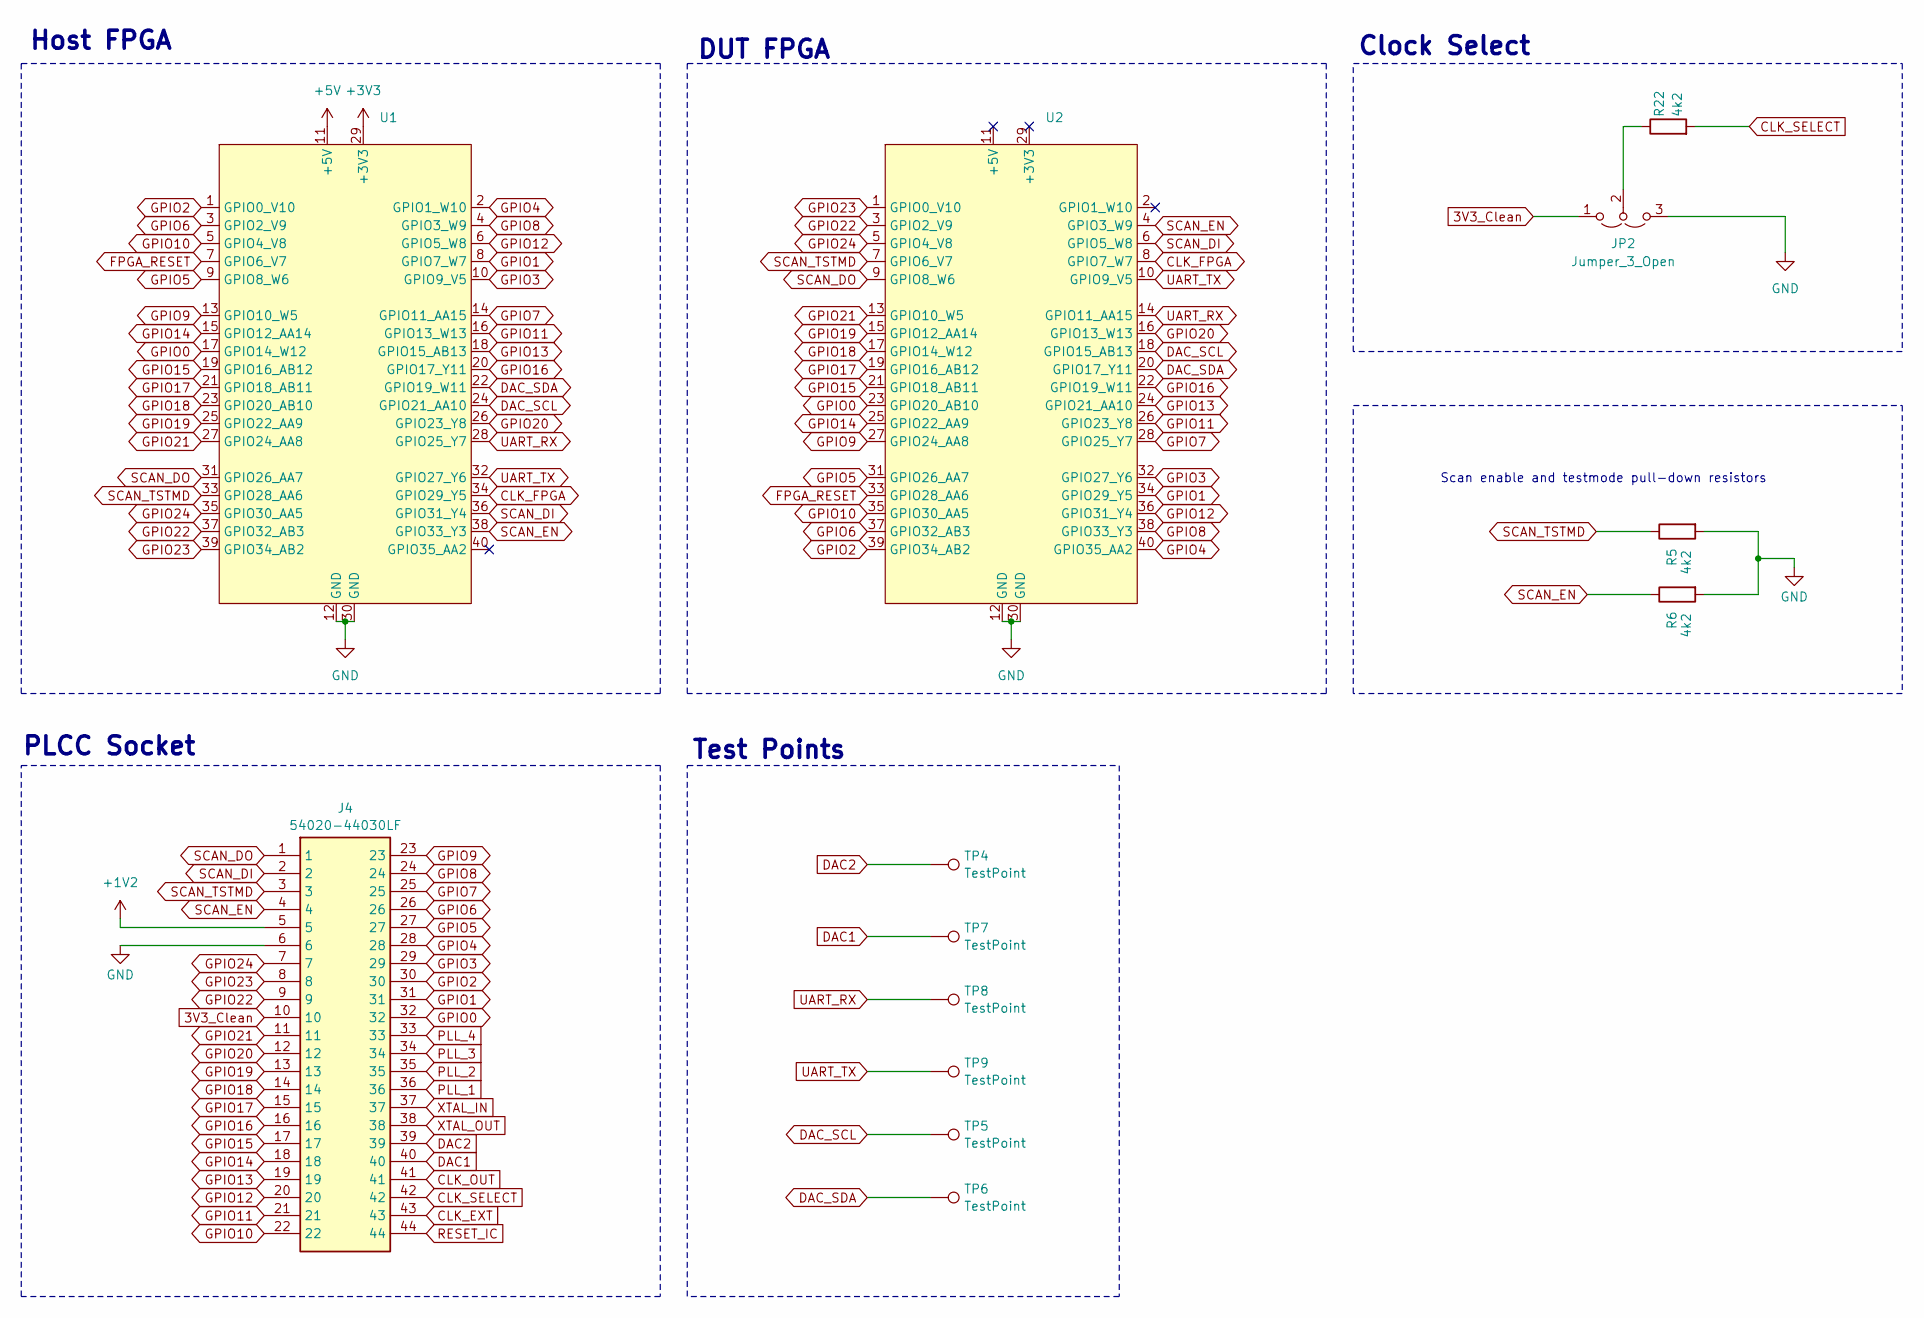
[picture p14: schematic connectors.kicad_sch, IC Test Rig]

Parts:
J4: 54020-44030LF; 5402044030LF; Manufacturer_Part_Number 54020-44030LF
JP2: Jumper_3_Open; PinHeader_1x03_P2.54mm_Vertical
R5, R6, R22: 4k2; R_0805_2012Metric_Pad1.20x1.40mm_HandSolder
TP4, TP5, TP6, TP7, TP8, TP9: TestPoint; TestPoint_Pad_D1.0mm
U1, U2: PinHeader_2x20_P2.54mm_Vertical

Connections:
3V3_Clean: J4.10, JP2.1 (A); also elsewhere on the board
+3V3: U1.29 (+3V3); also elsewhere on the board
+5V: U1.11 (+5V); also elsewhere on the board
CLK_EXT: J4.43; also elsewhere on the board
CLK_FPGA: U1.34 (GPIO29_Y5), U2.8 (GPIO7_W7); also elsewhere on the board
CLK_OUT: J4.41; also elsewhere on the board
CLK_SELECT: J4.42, R22.2
DAC1: J4.40, TP7.1; also elsewhere on the board
DAC2: J4.39, TP4.1; also elsewhere on the board
DAC_SCL: TP5.1, U1.24 (GPIO21_AA10), U2.18 (GPIO15_AB13); also elsewhere on the board
DAC_SDA: TP6.1, U1.22 (GPIO19_W11), U2.20 (GPIO17_Y11); also elsewhere on the board
FPGA_RESET: U1.7 (GPIO6_V7), U2.33 (GPIO28_AA6); also elsewhere on the board
GND: J4.6, JP2.3 (B), R5.2, R6.2, U1.12 (GND), U1.30 (GND), U2.12 (GND), U2.30 (GND); also elsewhere on the board
GPIO0: J4.32, U1.17 (GPIO14_W12), U2.23 (GPIO20_AB10)
GPIO1: J4.31, U1.8 (GPIO7_W7), U2.34 (GPIO29_Y5)
GPIO2: J4.30, U1.1 (GPIO0_V10), U2.39 (GPIO34_AB2)
GPIO3: J4.29, U1.10 (GPIO9_V5), U2.32 (GPIO27_Y6)
GPIO4: J4.28, U1.2 (GPIO1_W10), U2.40 (GPIO35_AA2)
GPIO5: J4.27, U1.9 (GPIO8_W6), U2.31 (GPIO26_AA7)
GPIO6: J4.26, U1.3 (GPIO2_V9), U2.37 (GPIO32_AB3)
GPIO7: J4.25, U1.14 (GPIO11_AA15), U2.28 (GPIO25_Y7)
GPIO8: J4.24, U1.4 (GPIO3_W9), U2.38 (GPIO33_Y3)
GPIO9: J4.23, U1.13 (GPIO10_W5), U2.27 (GPIO24_AA8)
GPIO10: J4.22, U1.5 (GPIO4_V8), U2.35 (GPIO30_AA5)
GPIO11: J4.21, U1.16 (GPIO13_W13), U2.26 (GPIO23_Y8)
GPIO12: J4.20, U1.6 (GPIO5_W8), U2.36 (GPIO31_Y4)
GPIO13: J4.19, U1.18 (GPIO15_AB13), U2.24 (GPIO21_AA10)
GPIO14: J4.18, U1.15 (GPIO12_AA14), U2.25 (GPIO22_AA9)
GPIO15: J4.17, U1.19 (GPIO16_AB12), U2.21 (GPIO18_AB11)
GPIO16: J4.16, U1.20 (GPIO17_Y11), U2.22 (GPIO19_W11)
GPIO17: J4.15, U1.21 (GPIO18_AB11), U2.19 (GPIO16_AB12)
GPIO18: J4.14, U1.23 (GPIO20_AB10), U2.17 (GPIO14_W12)
GPIO19: J4.13, U1.25 (GPIO22_AA9), U2.15 (GPIO12_AA14)
GPIO20: J4.12, U1.26 (GPIO23_Y8), U2.16 (GPIO13_W13)
GPIO21: J4.11, U1.27 (GPIO24_AA8), U2.13 (GPIO10_W5)
GPIO22: J4.9, U1.37 (GPIO32_AB3), U2.3 (GPIO2_V9)
GPIO23: J4.8, U1.39 (GPIO34_AB2), U2.1 (GPIO0_V10)
GPIO24: J4.7, U1.35 (GPIO30_AA5), U2.5 (GPIO4_V8)
unnamed: JP2.2 (C), R22.1
PLL_1: J4.36; also elsewhere on the board
PLL_2: J4.35; also elsewhere on the board
PLL_3: J4.34; also elsewhere on the board
PLL_4: J4.33; also elsewhere on the board
RESET_IC: J4.44; also elsewhere on the board
SCAN_DI: J4.2, U1.36 (GPIO31_Y4), U2.6 (GPIO5_W8)
SCAN_DO: J4.1, U1.31 (GPIO26_AA7), U2.9 (GPIO8_W6)
SCAN_EN: J4.4, R6.1, U1.38 (GPIO33_Y3), U2.4 (GPIO3_W9)
SCAN_TSTMD: J4.3, R5.1, U1.33 (GPIO28_AA6), U2.7 (GPIO6_V7)
SW1_OUT_1V2: J4.5; also elsewhere on the board
UART_RX: TP8.1, U1.28 (GPIO25_Y7), U2.14 (GPIO11_AA15); also elsewhere on the board
UART_TX: TP9.1, U1.32 (GPIO27_Y6), U2.10 (GPIO9_V5); also elsewhere on the board
XTAL_IN: J4.37; also elsewhere on the board
XTAL_OUT: J4.38; also elsewhere on the board

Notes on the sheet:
Host FPGA
Clock Select
DUT FPGA
Test Points
Scan enable and testmode pull-down resistors
PLCC Socket

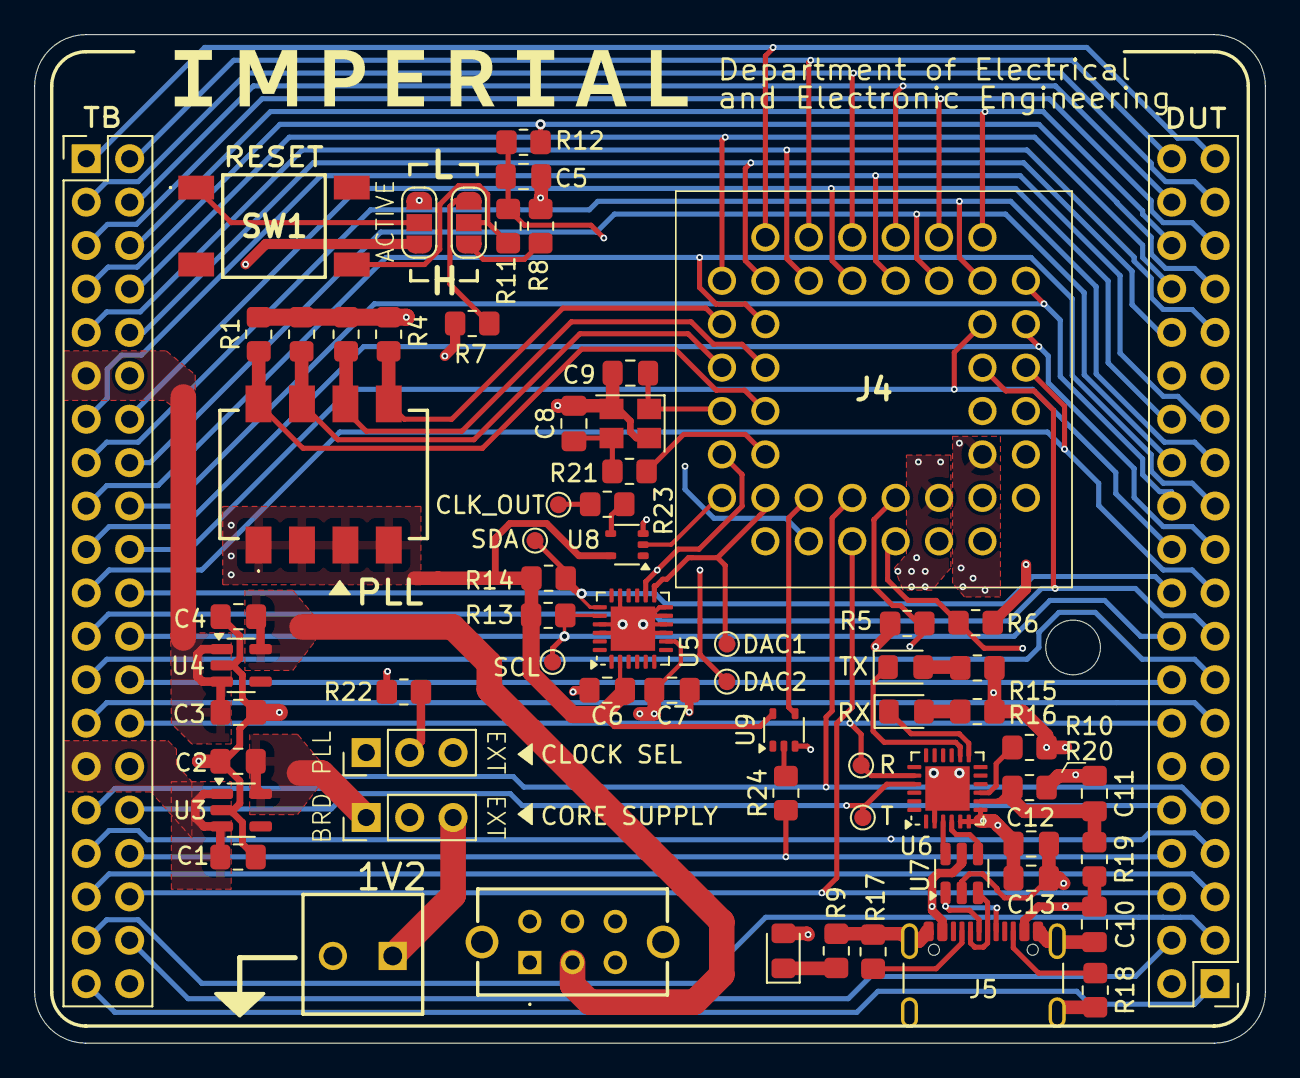
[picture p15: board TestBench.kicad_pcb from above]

Board: 4 copper layers, 72.0 x 59.0 mm, 68 parts (0 on the bottom side), 79 nets.

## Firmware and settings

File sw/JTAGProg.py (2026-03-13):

"""
JTAGProg.py — Host-side JTAG/UART programmer.

Drives the JTAG Engine firmware module via a USB-to-UART bridge (e.g. FTDI or
CP210x). Each byte sent over UART carries four JTAG clock cycles: the high
nibble encodes four TMS bits and the low nibble encodes four TDI bits.

Classes:
    JTAGDriver  — Builds TMS/TDI bitstreams, packs them into the nibble format
                  described above, and provides helpers for navigating the JTAG
                  FSM and shifting instruction/data registers.
    JTAGProg    — Opens a serial port and exchanges the packed byte stream with
                  the UART bridge. Read data is recovered by clocking dummy
                  bytes into the TAP and capturing the TDO bits returned by the
                  target.

Helper functions:
    load_32bit_hex_file        — Loads 32-bit hex words from a plain-text file.
    reconstruct_data_from_response — Parses a raw read response into a
                                     (data, address) tuple.
"""

import sys
import time
import serial
import argparse
import threading
import queue
from typing import List, Optional
import random


# JTAG constants matching the C++ defines
IR_NOP = 0x0
IR_MEM_CTRL = 0x1
IR_WRITE = 0x2
IR_READ = 0x3
IR_DONE = 0x4

ADDR_W = 10
DATA_W = 32
DR_W = ADDR_W + DATA_W


class JTAGDriver:
    def __init__(self):
        self.tms_bits: List[bool] = []
        self.tdi_bits: List[bool] = []

    def clear_stream(self):
        self.tms_bits.clear()
        self.tdi_bits.clear()

    @staticmethod
    def _pack_jtag_nibble(tms: int, tdi: int) -> int:
        return ((tms & 0x0F) << 4) | (tdi & 0x0F)

    def get_stream(self) -> List[int]:
        if len(self.tms_bits) != len(self.tdi_bits):
            raise RuntimeError("TMS/TDI size mismatch")

        out = []
        n = len(self.tms_bits)
        for i in range(0, n, 4):
            tms = 0
            tdi = 0
            for b in range(4):
                if i + b < n:
                    if self.tms_bits[i + b]:
                        tms |= (1 << b)
                    if self.tdi_bits[i + b]:
                        tdi |= (1 << b)
            out.append(self._pack_jtag_nibble(tms, tdi))

        return out

    def append_bits(self, tms_bits: List[bool], tdi_bits: List[bool]):
        if len(tms_bits) != len(tdi_bits):
            raise RuntimeError("TMS/TDI size mismatch")
        self.tms_bits.extend(tms_bits)
        self.tdi_bits.extend(tdi_bits)

    def append_repeat(self, tms: bool, tdi: bool, count: int):
        for _ in range(count):
            self.tms_bits.append(bool(tms))
            self.tdi_bits.append(bool(tdi))

    def shift_value(self, value: int, bitlen: int, exit_after: bool = True):
        for i in range(bitlen):
            bit = bool((value >> i) & 1)
            is_last_bit = (i == bitlen - 1)
            self.tms_bits.append(bool(exit_after and is_last_bit))
            self.tdi_bits.append(bit)

    def shift_instruction(self, ir: int, ir_len: int):
        # Move to Shift-IR
        self.append_repeat(1, 0, 2)  # Select-DR -> Select-IR
        self.append_repeat(0, 0, 1)  # Capture-IR
        self.append_repeat(0, 0, 1)  # Shift-IR

        # Shift IR LSB first
        self.shift_value(ir, ir_len, False)

        self.append_repeat(1, 0, 1)  # Exit IR
        self.append_repeat(1, 0, 1)  # Update-IR
        self.append_repeat(0, 0, 1)  # Run-Test/Idle

    def build_write_mem(self, ir: int, ir_len: int, dr_addr: int, dr_addr_len: int, dr_data: int, dr_data_len: int):
        self.shift_instruction(ir, ir_len)
        self.append_repeat(1, 0, 1)  # Select-DR
        self.append_repeat(0, 0, 1)  # Capture-DR
        self.append_repeat(0, 0, 1)  # Shift-DR

        # Shift DR data then address (LSB first as in the C++ driver)
        self.shift_value(dr_data, dr_data_len, False)
        self.shift_value(dr_addr, dr_addr_len, False)

        # Return to Run-Test/Idle
        self.append_repeat(1, 0, 1)  # Exit DR
        self.append_repeat(1, 0, 1)  # Update-DR
        self.append_repeat(0, 0, 1)  # Run-Test/Idle

    def build_read_mem(self, ir: int, ir_len: int, dr_addr: int, dr_addr_len: int):
        self.shift_instruction(ir, ir_len)
        self.append_repeat(1, 0, 1)  # Select-DR
        self.append_repeat(0, 0, 1)  # Capture-DR
        self.append_repeat(0, 0, 1)  # Shift-DR

        # Shift DR address
        self.shift_value(dr_addr, dr_addr_len, False)

        # Return to Run-Test/Idle
        self.append_repeat(1, 0, 1)  # Exit DR
        self.append_repeat(1, 0, 1)  # Update-DR
        self.append_repeat(0, 0, 1)  # Run-Test/Idle

    def shift_out_data(self, bitlen: int):
        # Wait for memory to process read (arbitrary cycles)
        self.append_repeat(0, 0, 5)

        # Move to Shift-DR to read data
        self.append_repeat(1, 0, 1)  # Select-DR
        self.append_repeat(0, 0, 1)  # Capture-DR
        self.append_repeat(0, 0, 1)  # Shift-DR

        # It's up to the testbench/host to clock out dummy bits if needed.

    def shift_out_data_exit(self):
        # Return to Run-Test/Idle after reading data
        self.append_repeat(1, 0, 1)  # Exit DR
        self.append_repeat(1, 0, 1)  # Update-DR
        self.append_repeat(0, 0, 2)  # Run-Test/Idle


class JTAGProg:
    def __init__(self, port: str, baud: int = 115200, timeout: float = 1.0, verbose: bool = False):
        self.port = port
        self.baud = baud
        self.timeout = timeout
        self.verbose = bool(verbose)
        self.ser = serial.Serial(port, baudrate=baud, timeout=0.01)
        # threaded reader to avoid missing RX bytes while writing
        self._rx_q: "queue.Queue[bytes]" = queue.Queue()
        self._stop_event = threading.Event()
        self._reader = threading.Thread(target=self._reader_thread, daemon=True)
        self._reader.start()

    def close(self):
        if self.ser and self.ser.is_open:
            self.ser.close()
        # stop reader thread
        try:
            self._stop_event.set()
            if hasattr(self, "_reader"):
                self._reader.join(timeout=0.1)
        except Exception:
            pass

    def _reader_thread(self):
        # continuously read single bytes and push them to the queue
        while not self._stop_event.is_set():
            try:
                b = self.ser.read(1)
                if b:
                    try:
                        self._rx_q.put(b, block=False)
                    except Exception:
                        pass
            except Exception:
                break

    def _clear_rx_queue(self):
        try:
            with self._rx_q.mutex:
                self._rx_q.queue.clear()
        except Exception:
            while not self._rx_q.empty():
                try:
                    self._rx_q.get_nowait()
                except Exception:
                    break

    def send_bytes(self, data: bytes):
        # Write and flush
        self.ser.write(data)
        self.ser.flush()

    def send_jtag_driver(self, driver: JTAGDriver):
        stream = driver.get_stream()
        data = bytes(stream)
        if getattr(self, "verbose", True):
            print(f"Sending {len(data)} bytes to {self.port}")
        self.send_bytes(data)

    def read_bytes(self, count: int, timeout_s: float = 1.0) -> bytes:
        deadline = time.time() + timeout_s
        buf = bytearray()
        while len(buf) < count and time.time() < deadline:
            chunk = self.ser.read(count - len(buf))
            if chunk:
                buf.extend(chunk)
        return bytes(buf)

    # High level helpers mirroring the C++ testbench actions
    def reset_jtag(self):
        drv = JTAGDriver()
        drv.append_repeat(1, 0, 5)
        drv.append_repeat(0, 0, 1)
        self.send_jtag_driver(drv)

    def prog_mode_on(self):
        drv = JTAGDriver()
        drv.shift_instruction(IR_MEM_CTRL, 4)
        self.send_jtag_driver(drv)

    def prog_mode_off(self):
        drv = JTAGDriver()
        drv.shift_instruction(IR_DONE, 4)
        self.send_jtag_driver(drv)

    def write_mem(self, addr: int, data: int):
        drv = JTAGDriver()
        drv.build_write_mem(IR_WRITE, 4, addr, ADDR_W, data, DATA_W)
        self.send_jtag_driver(drv)

    def read_mem(self, addr: int, expect_response_bytes: int = 6, resp_timeout: float = 1.0) -> bytes:
        # Build read command and send
        if getattr(self, "verbose", True):
            print(f"Requesting read from addr=0x{addr:02X}")
        drv = JTAGDriver()
        drv.build_read_mem(IR_READ, 4, addr, ADDR_W)
        self.send_jtag_driver(drv)
        # Prepare to shift out read data: send pre-shift control bytes, then
        # send dummy bytes (0x00) while reading one response byte per dummy
        # byte, then send the post-shift (exit) control bytes.

        # time.sleep(0.015)


        # pre-shift (enter Shift-DR and any wait cycles)
        drv_pre = JTAGDriver()
        drv_pre.shift_out_data(DR_W)
        pre_stream = drv_pre.get_stream()
        if pre_stream:
            self.send_bytes(bytes(pre_stream))

        # clear any stale data and the reader queue before starting to read response bytes
        time.sleep(0.01)
        self.ser.reset_input_buffer()
        self._clear_rx_queue()

        # send dummy bytes one at a time and read one response byte per dummy
        # time.sleep(0.005)
        # self.ser.reset_input_buffer()


        resp_buf = bytearray()

        # Send two dummy bites for each expected response byte
        self.send_bytes(b"\x00" * (expect_response_bytes * 2))

        # post-shift (exit DR back to Run-Test/Idle)
        drv_post = JTAGDriver()
        drv_post.shift_out_data_exit()
        post_stream = drv_post.get_stream()
        if post_stream:
            self.send_bytes(bytes(post_stream))
        else:
            if getattr(self, "verbose", True):
                print("Warning: no post-shift stream generated")

        # Drain any bytes in the reader queue into resp_buf
        # (capture all bytes received since last clear)
        try:
            # brief pause to allow any in-flight bytes to arrive
            time.sleep(0.01)
        except Exception:
            pass

        # Drain queue without blocking
        while True:
            try:
                b = self._rx_q.get_nowait()
            except queue.Empty:
                break
            resp_buf.extend(b)

        # Print debug info: bytes and count
        # print(f"Received {len(resp_buf)} bytes: {resp_buf.hex()}")

        return bytes(resp_buf)


def load_32bit_hex_file(path: str) -> List[int]:
    out: List[int] = []
    with open(path, "r") as f:
        for ln in f:
            s = ln.strip()
            if not s:
                continue
            # allow 0x prefix or plain hex
            if s.startswith("0x") or s.startswith("0X"):
                s = s[2:]
            # remove comments after a space
            if " " in s:
                s = s.split(" ", 1)[0]
            try:
                val = int(s, 16) & 0xFFFFFFFF
            except ValueError:
                raise ValueError(f"Invalid hex in data file: {ln.strip()}")
            out.append(val)
    return out

## Genearate some dummy data for testing instead of loading from file
def generate_dummy_data(count: int, seed: int) -> List[int]:
    r = random.Random(seed)
    return [r.getrandbits(32) for _ in range(count)]

def human_bytes(num_bytes: int) -> str:
    """Convert bytes to human-readable format."""
    for unit in ['B', 'KB', 'MB', 'GB']:
        if num_bytes < 1024.0:
            return f"{num_bytes:.2f} {unit}"
        num_bytes /= 1024.0
    return f"{num_bytes:.2f} TB"

def reconstruct_data_from_response(resp: bytes) -> int:
    # Reconstruct data (bytes 0..3 are data LSB..MSB)
    # return value and address separately
    data_val = 0
    for j in range(3, -1, -1):
        data_val <<= 8
        data_val |= resp[j]
    addr_val = (resp[5] << 8) | resp[4]
    return data_val, addr_val


def main():
    parser = argparse.ArgumentParser(description="Host JTAG UART programmer")
    parser.add_argument("port", help="Serial port to open (e.g. /dev/ttyUSB0)")
    parser.add_argument("datafile", nargs='?', help="Text file containing 32-bit hex words, one per line (required unless --test-mode is used)")
    parser.add_argument("--baud", type=int, default=115200, help="Baud rate for the serial port")
    parser.add_argument("--start-addr", type=int, default=0)
    parser.add_argument("--verbose", action="store_true", help="Enable verbose JTAG driver prints")
    parser.add_argument("--test-mode", action="store_true", help="Run in test mode with generated dummy data instead of loading from file")
    parser.add_argument("--word-count", type=int, default=128, help="Number of words to generate in test mode (default 128)")
    args = parser.parse_args()

    # Validate that datafile is provided if not in test mode
    if not args.test_mode and not args.datafile:
        parser.error("datafile is required unless --test-mode is used")

    # For testing, generate some dummy data instead of loading from file
    if args.test_mode:
        words = generate_dummy_data(args.word_count, seed=42)
    else:
        words = load_32bit_hex_file(args.datafile)


    p = JTAGProg(args.port, baud=args.baud, verbose=args.verbose)
    try:
        print("Resetting JTAG TAP...")
        p.reset_jtag()
        time.sleep(0.05)
        print("Entering programming mode...")
        p.prog_mode_on()


        # progress counters
        written_so_far = 0
        verified_so_far = 0
        # throttle updates to a reasonable number (approx 200 updates)
        write_update_interval = max(1, len(words) // 200)
        read_update_interval = max(1, len(words) // 200)

        def _print_progress(stage: str, current: int, total: int):
            pct = (current * 100.0 / total) if total else 100.0
            # carriage-return update
            sys.stdout.write(f"\r{stage}: {pct:6.2f}% ({current}/{total})")
            sys.stdout.flush()

        # write words sequentially starting at start-addr
        t0 = time.time()
        for i, w in enumerate(words):
            addr = args.start_addr + i
            if getattr(p, "verbose", True):
                print(f"Writing addr=0x{addr:02X} data=0x{w:08X}")
            p.write_mem(addr, w)
            written_so_far += 1
            # throttled progress update
            if written_so_far % write_update_interval == 0 or (i + 1) == len(words):
                _print_progress("Writing", written_so_far, len(words))
            time.sleep(0.005)

        t1 = time.time()
        write_time = t1 - t0

        sys.stdout.write("\n\n")
        # Read and verify all the written words
        print("Verifying all entries...")
        errors = 0
        for i in range(len(words)):
            addr = args.start_addr + i
            resp = p.read_mem(addr, expect_response_bytes=6, resp_timeout=0.5)
            verified_so_far += 1
            # throttled progress update
            if (verified_so_far % read_update_interval) == 0 or verified_so_far == len(words):
                _print_progress("Verifying", verified_so_far, len(words))
            if len(resp) < 6:
                print(f"Addr 0x{addr:02X}: no response (len={len(resp)})")
                errors += 1
                continue
            data_val, addr_resp = reconstruct_data_from_response(resp)
            expected_val = words[i]
            if addr_resp != addr or data_val != expected_val:
                print(f"Addr 0x{addr:02X}: MISMATCH! Expected 0x{expected_val:08X}, got 0x{data_val:08X}")
                errors += 1
            else:
                if getattr(p, "verbose", True):
                    print(f"Addr 0x{addr:02X}: OK Data: 0x{data_val:08X}")

        read_time = time.time() - t1

        sys.stdout.write("\n\n")

        print(f"Verification complete. Errors found: {errors}")
        print("Exiting programming mode...")
        p.prog_mode_off()


        print("\nSummary:")
        print(f"  Total words: {len(words)}")
        print(f"  Total bytes: {len(words)*4} ({human_bytes(len(words)*4)})")
        print(f"  Total write time: {write_time:.3f}s")
        if write_time > 0:
            print(f"  Write throughput: {(len(words)*4)/1024/write_time:.2f} KB/s")
        print(f"  Total read time: {read_time:.3f}s")
        if read_time > 0:
            print(f"  Read throughput: {(len(words)*4)/1024/read_time:.2f} KB/s")
        print(f"  Total errors: {errors}")

        if errors:
            print("One or more verification errors detected.")
            sys.exit(2)
        else:
            print("All data verified successfully.")

    finally:
        p.close()


if __name__ == "__main__":
    main()

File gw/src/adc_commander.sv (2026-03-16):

`timescale 1ns/1ps

module adc_commander #(
    parameter CLK_FREQ = 10_000_000, // 10 MHz
    parameter I2C_FREQ = 100_000      // 100 kHz
)(
    input  logic i_clk,
    input  logic i_rst_n,
    output logic o_done,
    output logic o_ack_error,

    // I2C bus
    inout  wire  scl,
    inout  wire  sda
);

    // Command memory parameters
    localparam NUM_CMDS = 6;
    localparam ADC_ADDR = 7'b1001000; // ADC I2C address (0x48)

    // DAC values to be sent to the ADC (12-bit values)
    // Reference voltage is 1.2v. 
    // Set the values in a 12 bit format with the maximum value of 4095 corresponding to 1.2v
    localparam DAC1_VALUE = 12'd2048; 
    localparam DAC2_VALUE = 12'd1024; 


    // Command memory array [address, data]
    logic [7:0] cmd_mem [0:NUM_CMDS-1];
    
    initial begin
        cmd_mem[0] = 8'b00000111;               // Write Channel H
        cmd_mem[1] = DAC1_VALUE[11:4];          // MSB of data
        cmd_mem[2] = {DAC1_VALUE[3:0],4'b0000}; // LSB of data
        cmd_mem[3] = 8'b00000101;               // Write Channel F
        cmd_mem[4] = DAC2_VALUE[11:4];          // MSB of data
        cmd_mem[5] = {DAC2_VALUE[3:0],4'b0000}; // LSB of data
    end

    typedef enum logic [2:0] {
        IDLE,
        SET_DAC1_START,
        SEND_DAC1_DATA,
        SET_DAC2_START,
        SEND_DAC2_DATA,
        DONE
    } state_t;

    state_t state, next_state;
    
    logic [7:0] cmd_index, cmd_index_next;

    logic       master_start;
    logic       master_stop, master_stop_next;
    logic [6:0] master_addr;
    logic       master_op;
    logic [7:0] master_data_wr;
    logic [7:0] master_data_rd;
    logic       master_busy;
    logic       master_busy_prev;
    logic       master_tx_complete;

    i2c_master 
    #(
        .CLK_FREQ(CLK_FREQ),
        .I2C_FREQ(I2C_FREQ)
    ) i2c_master_inst (
        .i_clk(i_clk),
        .i_rst_n(i_rst_n),
        .i_start(master_start),
        .i_addr(master_addr),
        .i_op(master_op),
        .i_stop(master_stop),
        .i_data_wr(master_data_wr),
        .o_data_rd(master_data_rd),
        .o_busy(master_busy),
        .o_ack_error(o_ack_error),
        .o_data_tx_complete(master_tx_complete),
        .scl(scl),
        .sda(sda)
    );

    always_ff @(posedge i_clk or negedge i_rst_n) begin
        if (!i_rst_n) begin
            state <= IDLE;
            cmd_index <= 0;
            master_busy_prev <= 0;
            master_stop <= 0;
        end else begin
            state <= next_state;
            cmd_index <= cmd_index_next;
            master_busy_prev <= master_busy;
            master_stop <= master_stop_next;
        end
    end

    always_comb begin
        next_state = state;
        cmd_index_next = cmd_index;
        master_start = 1'b0;
        master_addr = ADC_ADDR;
        master_op = 1'b0; // Write
        master_data_wr = cmd_mem[cmd_index[2:0]]; 
        o_done = 1'b0;
        master_stop_next = 1'b0;
       
        case (state)
            IDLE: begin
                cmd_index_next = 0;
                next_state = SET_DAC1_START;
            end


            SET_DAC1_START: begin
                master_start = 1'b1;
                next_state = SEND_DAC1_DATA;
            end

            SEND_DAC1_DATA: begin
                if(master_tx_complete) begin
                    if(o_ack_error) begin
                        next_state = DONE; // Stop on ACK error
                    end else begin
                        cmd_index_next = cmd_index + 1;
                        if(cmd_index_next == 3) begin
                            next_state = SET_DAC2_START;
                            master_stop_next = 1'b1; // Stop after first DAC commands
                        end
                    end
                end
            end

            SET_DAC2_START: begin
                master_start = 1'b1;
                if(master_busy_prev && !master_busy) begin
                    next_state = SEND_DAC2_DATA;
                    cmd_index_next = 3; // Start of second DAC commands
                end
            end

            SEND_DAC2_DATA: begin
                if(master_tx_complete) begin
                    if(o_ack_error) begin
                        next_state = DONE; // Stop on ACK error
                    end else begin
                        cmd_index_next = cmd_index + 1;
                        if(cmd_index_next == 6) begin
                            next_state = DONE;
                            master_stop_next = 1'b1; // Stop after first DAC commands
                        end
                    end
                end
            end

            DONE: begin
                o_done = 1'b1;
                next_state = DONE;
            end

            default: begin
                next_state = IDLE;
            end
        endcase
    end

endmodule

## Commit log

2026-03-12 adjusted adc commander
2026-03-26 added board components reference view pdf
